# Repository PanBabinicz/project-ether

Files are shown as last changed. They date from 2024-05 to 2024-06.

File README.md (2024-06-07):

# PROJECT ETHER

## ❓ What is ETHER?

▶️ [Cambridge dictionary:](https://dictionary.cambridge.org/dictionary/english/ether)

> the sky or the air, especially considered as being full of radio waves

▶️ [The fantasy wiki with fictional characters:](https://gods-and-demons.fandom.com/wiki/Aether_(Deity))

> ***"Hi! My name is Aether and I am one of the Protogenoi. I'm the Lord of the stratosphere,
> or as I call it, the Upper Air, Bringer of Light, and the eldest son of Darkness and Night.
> Today, I will be your captain and guide as we explore the strange but fantastic world of Olympus.
> So hold tight to your seatbelts, 'cause this is gonna be one hell of a ride!"***
>
> Aether the god himself is the embodiment of the upper sky, the stratosphere is his domain and 
> with it the air that the gods breathe from. Every world has its own air for its creatures to breathe,
> the underworld is breathed by its monsters, the Human Realm is breathed by its humans, and the Skyland 
> is breathed by the divine beings who control reality; that is the air that Aether controls. It's not just 
> the air of Skyland that he controls however, a portion of the Earth's sky belongs to him as well. The Earthly sky 
> isn't the only cosmic body that Aether can control, the Moon, Stars, Clouds, and partially even the Sun can be controlled by him.

▶️ [The Concept of 'Ether' in Radio Wave Propagation:]

> In the context of radio waves, "ether" refers to the medium through which radio waves propagate.
> This medium is often conceptualized as the space surrounding us, particularly the atmosphere or the open air.
> In the early days of radio communication, scientists believed that radio waves traveled through a substance called
> "ether," filling the space much like air or water fills physical space. While the concept of a physical ether 
> was later debunked by advancements in physics, the term "ether" is still used metaphorically to describe the 
> invisible medium through which radio waves travel.

## ⚒️  Project goal 

> ***The main goal of the project is to create a comprehensive air quality monitoring system, 
> based on the ESP32 platform and integrated with OpenHAB and Grafana. The plan involves the development of 
> a dedicated hardware device equipped with ESP32, appropriate sensors measuring carbon dioxide, temperature, and humidity, 
> as well as a power supply unit. Additionally, the project envisages the use of the MQTT protocol,
> enabling efficient communication between devices, ensuring fast and reliable transmission of sensor data to the server.
> OpenHAB and Grafana will be deployed on the Raspberry Pi platform.***
>

> [!NOTE]
> **Please bear in mind that the project was primarily created for enjoyment and educational endeavors.**

## 🔌 Hardware

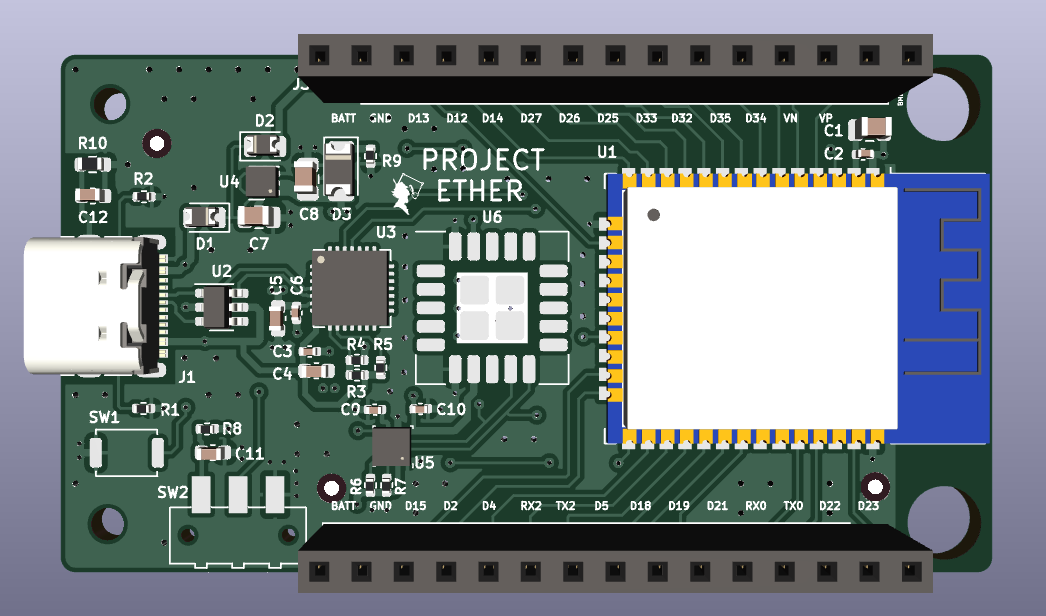
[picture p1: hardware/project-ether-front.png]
Front


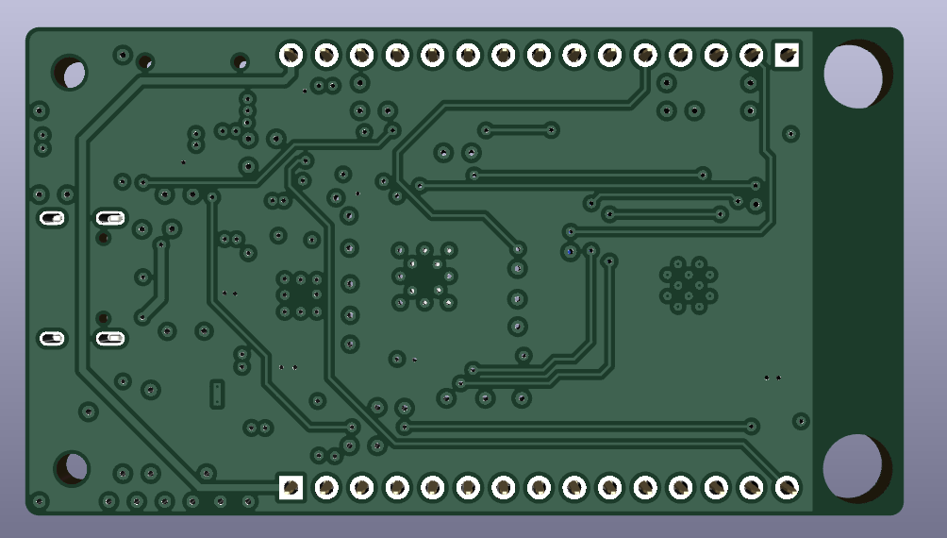
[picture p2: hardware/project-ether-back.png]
Back


> The hardware for this project was meticulously designed using KiCad, a popular open-source electronic design automation software. 
> The board is a 4-layer design featuring the ESP32-WROOM-32 module at its core. Additionally, it integrates key sensors such as the BME280 and SCD41,
> enabling environmental monitoring capabilities.
>
> The device can be conveniently powered either via USB Type-C connection or an external battery, providing flexibility for different usage scenarios and environments.

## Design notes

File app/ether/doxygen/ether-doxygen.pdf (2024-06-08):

## PROJECT ETHER

Generated by Doxygen 1.11.0

i

1 Data Structure Index | 1
2 File Index | 3
3 Data Structure Documentation | 5

Generated by Doxygen

ii

iii

iv

4 File Documentation | 27

v

vi

vii

viii

ix

x

Index | 81

# Chapter 1

# Data Structure Index

## 1.1 Data Structures

Here are the data structures with brief descriptions:

bme280_compensator_t

bme280_humidity_t

bme280_measurements_t

bme280_pressure_t

bme280_settings_t

bme280_temperature_t

ether_descriptor_t

ether_measurements_t

ether_settings_t

ether_state_machine_t

ether_t
Main structure for ETHER containing measurements, descriptors, settings, and state machine . 16 i2c_controller_descriptor_t

mqtt_controller_descriptor_t

pms7003_frame_answer_t

pms7003_frame_request_t

pms7003_measurements_t

uart_controller_descriptor_t

wifi_controller_descriptor_t

### 2 Data Structure Index

# Chapter 2

# File Index

## 2.1 File List

Here is a list of all files with brief descriptions:

### 4 File Index

# Chapter 3

# Data Structure Documentation

## 3.1 bme280_compensator_t Struct Reference

Structure for the BME280 sensor compensator data.

#include <bme280.h>

Data Fields

- uint16_t dig_t1
- int16_t dig_t2
- int16_t dig_t3
- uint16_t dig_p1
- int16_t dig_p2
- int16_t dig_p3
- int16_t dig_p4
- int16_t dig_p5
- int16_t dig_p6
- int16_t dig_p7
- int16_t dig_p8
- int16_t dig_p9
- uint8_t dig_h1
- int16_t dig_h2
- uint8_t dig_h3
- int16_t dig_h4
- int16_t dig_h5
- int8_t dig_h6

### 3.1.1 Detailed Description

Structure for the BME280 sensor compensator data.

### 6 Data Structure Documentation

### 3.1.2 Field Documentation

### 3.1.2.1 dig_h1

uint8_t dig_h1

Humidity compensation value H1.

### 3.1.2.2 dig_h2

int16_t dig_h2

Humidity compensation value H2.

### 3.1.2.3 dig_h3

uint8_t dig_h3

Humidity compensation value H3.

### 3.1.2.4 dig_h4

int16_t dig_h4

Humidity compensation value H4.

### 3.1.2.5 dig_h5

int16_t dig_h5

Humidity compensation value H5.

### 3.1.2.6 dig_h6

int8_t dig_h6

Humidity compensation value H6.

### 3.1.2.7 dig_p1

uint16_t dig_p1

Pressure compensation value P1.

3.1 bme280_compensator_t Struct Reference | 7

### 3.1.2.8 dig_p2

int16_t dig_p2

Pressure compensation value P2.

### 3.1.2.9 dig_p3

int16_t dig_p3

Pressure compensation value P3.

### 3.1.2.10 dig_p4

int16_t dig_p4

Pressure compensation value P4.

### 3.1.2.11 dig_p5

int16_t dig_p5

Pressure compensation value P5.

### 3.1.2.12 dig_p6

int16_t dig_p6

Pressure compensation value P6.

### 3.1.2.13 dig_p7

int16_t dig_p7

Pressure compensation value P7.

### 3.1.2.14 dig_p8

int16_t dig_p8

Pressure compensation value P8.

### 3.1.2.15 dig_p9

int16_t dig_p9

Pressure compensation value P9.

### 8 Data Structure Documentation

### 3.1.2.16 dig_t1

uint16_t dig_t1

Temperature compensation value T1.

### 3.1.2.17 dig_t2

int16_t dig_t2

Temperature compensation value T2.

### 3.1.2.18 dig_t3

int16_t dig_t3

Temperature compensation value T3.

The documentation for this struct was generated from the following file:

- bme280.h

## 3.2 bme280_humidity_t Struct Reference

Structure for the BME280 sensor humidity data.

#include <bme280.h>

Data Fields

- uint8_t msb
- uint8_t lsb
- double compensated

### 3.2.1 Detailed Description

Structure for the BME280 sensor humidity data.

### 3.2.2 Field Documentation

### 3.2.2.1 compensated

double compensated

Compensated humidity value.

3.3 bme280_measurements_t Struct Reference | 9

### 3.2.2.2 lsb

uint8_t lsb

Least significant byte.

### 3.2.2.3 msb

uint8_t msb

Most significant byte.

The documentation for this struct was generated from the following file:

- bme280.h

## 3.3 bme280_measurements_t Struct Reference

Structure for BME280 sensor measurements.

#include <bme280.h>

Data Fields

- bme280_humidity_t humidity
- bme280_pressure_t pressure
- bme280_temperature_t temperature
- bme280_compensator_t compensator

### 3.3.1 Detailed Description

Structure for BME280 sensor measurements.

### 3.3.2 Field Documentation

### 3.3.2.1 compensator

bme280_compensator_t compensator

Compensator data.

### 3.3.2.2 humidity

bme280_humidity_t humidity

Humidity data.

### 10 Data Structure Documentation

### 3.3.2.3 pressure

bme280_pressure_t pressure

Pressure data.

### 3.3.2.4 temperature

bme280_temperature_t temperature

Temperature data.

The documentation for this struct was generated from the following file:

- bme280.h

## 3.4 bme280_pressure_t Struct Reference

Structure for the BME280 sensor pressure data.

#include <bme280.h>

Data Fields

- uint8_t msb
- uint8_t lsb
- uint8_t xlsb
- double compensated

### 3.4.1 Detailed Description

Structure for the BME280 sensor pressure data.

### 3.4.2 Field Documentation

### 3.4.2.1 compensated

double compensated

Compensated pressure value.

### 3.4.2.2 lsb

uint8_t lsb

Least significant byte.

3.5 bme280_settings_t Struct Reference | 11

### 3.4.2.3 msb

uint8_t msb

Most significant byte.

### 3.4.2.4 xlsb

uint8_t xlsb

Extended least significant byte.

The documentation for this struct was generated from the following file:

- bme280.h

## 3.5 bme280_settings_t Struct Reference

Structure for the BME280 sensor settings.

#include <bme280.h>

Data Fields

- uint8_t ctrl_hum
- uint8_t ctrl_meas
- uint8_t config

### 3.5.1 Detailed Description

Structure for the BME280 sensor settings.

### 3.5.2 Field Documentation

### 3.5.2.1 config

uint8_t config

Configuration register value.

### 3.5.2.2 ctrl_hum

uint8_t ctrl_hum

Control humidity register value.

### 12 Data Structure Documentation

### 3.5.2.3 ctrl_meas

uint8_t ctrl_meas

Control measurement register value.

The documentation for this struct was generated from the following file:

- bme280.h

## 3.6 bme280_temperature_t Struct Reference

Structure for the BME280 sensor temperature data.

#include <bme280.h>

Data Fields

- uint8_t msb
- uint8_t lsb
- uint8_t xlsb
- double compensated

### 3.6.1 Detailed Description

Structure for the BME280 sensor temperature data.

### 3.6.2 Field Documentation

### 3.6.2.1 compensated

double compensated

Compensated temperature value.

### 3.6.2.2 lsb

uint8_t lsb

Least significant byte.

### 3.6.2.3 msb

uint8_t msb

Most significant byte.

3.7 ether_descriptor_t Struct Reference | 13

### 3.6.2.4 xlsb

uint8_t xlsb

Extended least significant byte.

The documentation for this struct was generated from the following file:

- bme280.h

## 3.7 ether_descriptor_t Struct Reference

Structure to hold various controller descriptors.

#include <ether.h>

Data Fields

- i2c_controller_descriptor_t i2c_controller
- mqtt_controller_descriptor_t mqtt_controller
- uart_controller_descriptor_t uart_controller
- wifi_controller_descriptor_t wifi_controller

### 3.7.1 Detailed Description

Structure to hold various controller descriptors.

### 3.7.2 Field Documentation

### 3.7.2.1 i2c_controller

i2c_controller_descriptor_t i2c_controller

I2C controller descriptor.

### 3.7.2.2 mqtt_controller

mqtt_controller_descriptor_t mqtt_controller

MQTT controller descriptor.

### 3.7.2.3 uart_controller

uart_controller_descriptor_t uart_controller

UART controller descriptor.

### 14 Data Structure Documentation

### 3.7.2.4 wifi_controller

wifi_controller_descriptor_t wifi_controller

WIFI controller descriptor.

The documentation for this struct was generated from the following file:

- ether.h

## 3.8 ether_measurements_t Struct Reference

Structure to store PMS7003 and BME280 sensors measurements.

#include <ether.h>

Data Fields

- pms7003_measurements_t pms7003
- bme280_measurements_t bme280

### 3.8.1 Detailed Description

Structure to store PMS7003 and BME280 sensors measurements.

### 3.8.2 Field Documentation

### 3.8.2.1 bme280

bme280_measurements_t bme280

BME280 measurements.

### 3.8.2.2 pms7003

pms7003_measurements_t pms7003

PMS7003 measurements.

The documentation for this struct was generated from the following file:

- ether.h

3.9 ether_settings_t Struct Reference | 15

## 3.9 ether_settings_t Struct Reference

Structure for ETHER settings.

#include <ether.h>

Data Fields

- bme280_settings_t bme280

### 3.9.1 Detailed Description

Structure for ETHER settings.

### 3.9.2 Field Documentation

### 3.9.2.1 bme280

bme280_settings_t bme280

BME280 sensor settings.

The documentation for this struct was generated from the following file:

- ether.h

## 3.10 ether_state_machine_t Struct Reference

Structure to hold the state machine for PMS7003 and BME280 sensors.

#include <ether.h>

Data Fields

- pms7003_state_t pms7003
- bme280_state_t bme280

### 3.10.1 Detailed Description

Structure to hold the state machine for PMS7003 and BME280 sensors.

### 16 Data Structure Documentation

### 3.10.2 Field Documentation

### 3.10.2.1 bme280

bme280_state_t bme280

BME280 sensor state.

### 3.10.2.2 pms7003

pms7003_state_t pms7003

PMS7003 sensor state.

The documentation for this struct was generated from the following file:

- ether.h

## 3.11 ether_t Struct Reference

Main structure for ETHER containing measurements, descriptors, settings, and state machine.

#include <ether.h>

Data Fields

- ether_measurements_t measurements
- ether_descriptor_t descriptor
- ether_settings_t settings
- ether_state_machine_t state_machine

### 3.11.1 Detailed Description

Main structure for ETHER containing measurements, descriptors, settings, and state machine.

### 3.11.2 Field Documentation

### 3.11.2.1 descriptor

ether_descriptor_t descriptor

Controller descriptors.

3.12 i2c_controller_descriptor_t Struct Reference | 17

### 3.11.2.2 measurements

ether_measurements_t measurements

Measurements data.

### 3.11.2.3 settings

ether_settings_t settings

Settings data.

### 3.11.2.4 state_machine

ether_state_machine_t state_machine

State machine data.

The documentation for this struct was generated from the following file:

- ether.h

## 3.12 i2c_controller_descriptor_t Struct Reference

Structure for I2C controller descriptor.

#include <i2c_controller.h>

Data Fields

- i2c_config_t config
- i2c_port_t i2c_num

### 3.12.1 Detailed Description

Structure for I2C controller descriptor.

### 3.12.2 Field Documentation

### 3.12.2.1 config

i2c_config_t config

I2C configuration.

### 18 Data Structure Documentation

### 3.12.2.2 i2c_num

i2c_port_t i2c_num

I2C port number.

The documentation for this struct was generated from the following file:

- i2c_controller.h

## 3.13 mqtt_controller_descriptor_t Struct Reference

Structure for MQTT controller descriptor.

#include <mqtt_controller.h>

Data Fields

- esp_mqtt_client_config_t client_config
- esp_mqtt_client_handle_t client_handle
- mqtt_controller_event_handler_t event_handler

### 3.13.1 Detailed Description

Structure for MQTT controller descriptor.

### 3.13.2 Field Documentation

### 3.13.2.1 client_config

esp_mqtt_client_config_t client_config

MQTT client configuration.

### 3.13.2.2 client_handle

esp_mqtt_client_handle_t client_handle

MQTT client handle.

### 3.13.2.3 event_handler

mqtt_controller_event_handler_t event_handler

MQTT event handler.

The documentation for this struct was generated from the following file:

- mqtt_controller.h

3.14 pms7003_frame_answer_t Union Reference | 19

## 3.14 pms7003_frame_answer_t Union Reference

Union representing a PMS7003 frame answer.

#include <pms7003.h>

Public Member Functions

- struct {
uint8_t start_byte_1
uint8_t start_byte_2
uint16_t length
uint16_t data_pm1_standard uint16_t data_pm25_standard uint16_t data_pm10_standard uint16_t data_pm1_atmospheric uint16_t data_pm25_atmospheric uint16_t data_concentration_unit uint16_t data_particles_300nm uint16_t data_particles_500nm uint16_t data_particles_1000nm uint16_t data_particles_2500nm uint16_t data_particles_5000nm uint16_t data_particles_10000nm uint16_t reserved
uint16_t check_code
} __attribute__ ((packed))

Data Fields

- uint8_t buffer_answer [PMS7003_FRAME_ANSWER_SIZE]

### 3.14.1 Detailed Description

Union representing a PMS7003 frame answer.

### 3.14.2 Member Function Documentation

### 3.14.2.1 __attribute__()

struct pms7003_frame_answer_t::@1 __attribute__ (

(packed) )

### 3.14.3 Field Documentation

### 3.14.3.1 buffer_answer

uint8_t buffer_answer[PMS7003_FRAME_ANSWER_SIZE]

Buffer for answer frame.

### 20 Data Structure Documentation

### 3.14.3.2 check_code

uint16_t check_code

Checksum code.

### 3.14.3.3 data_concentration_unit

uint16_t data_concentration_unit

Concentration unit.

### 3.14.3.4 data_particles_10000nm

uint16_t data_particles_10000nm

Particles count for 10µm.

### 3.14.3.5 data_particles_1000nm

uint16_t data_particles_1000nm

Particles count for 1.0µm.

### 3.14.3.6 data_particles_2500nm

uint16_t data_particles_2500nm

Particles count for 2.5µm.

### 3.14.3.7 data_particles_300nm

uint16_t data_particles_300nm

Particles count for 0.3µm.

### 3.14.3.8 data_particles_5000nm

uint16_t data_particles_5000nm

Particles count for 5.0µm.

### 3.14.3.9 data_particles_500nm

uint16_t data_particles_500nm

Particles count for 0.5µm.

3.14 pms7003_frame_answer_t Union Reference | 21

### 3.14.3.10 data_pm10_standard

uint16_t data_pm10_standard

PM10 concentration (standard particles).

### 3.14.3.11 data_pm1_atmospheric

uint16_t data_pm1_atmospheric

PM1.0 concentration (atmospheric particles).

### 3.14.3.12 data_pm1_standard

uint16_t data_pm1_standard

PM1.0 concentration (standard particles).

### 3.14.3.13 data_pm25_atmospheric

uint16_t data_pm25_atmospheric

PM2.5 concentration (atmospheric particles).

### 3.14.3.14 data_pm25_standard

uint16_t data_pm25_standard

PM2.5 concentration (standard particles).

### 3.14.3.15 length

uint16_t length

Length of the frame.

### 3.14.3.16 reserved

uint16_t reserved

Reserved bytes.

### 3.14.3.17 start_byte_1

uint8_t start_byte_1

Start byte 1.

### 22 Data Structure Documentation

### 3.14.3.18 start_byte_2

uint8_t start_byte_2

Start byte 2.

The documentation for this union was generated from the following file:

- pms7003.h

## 3.15 pms7003_frame_request_t Union Reference

Union representing a PMS7003 frame request.

#include <pms7003.h>

Public Member Functions

- struct {
const uint8_t start_byte_1 const uint8_t start_byte_2 uint8_t command
uint8_t data_h
uint8_t data_l
uint8_t lrch
uint8_t lrcl
} __attribute__ ((packed))

Data Fields

- uint8_t buffer_request [PMS7003_FRAME_REQUEST_SIZE]

### 3.15.1 Detailed Description

Union representing a PMS7003 frame request.

### 3.15.2 Member Function Documentation

### 3.15.2.1 __attribute__()

struct pms7003_frame_request_t::@0 __attribute__ (

(packed) )

3.15 pms7003_frame_request_t Union Reference | 23

### 3.15.3 Field Documentation

### 3.15.3.1 buffer_request

uint8_t buffer_request[PMS7003_FRAME_REQUEST_SIZE]

Buffer for request frame.

### 3.15.3.2 command

uint8_t command

Command byte.

### 3.15.3.3 data_h

uint8_t data_h

Data high byte.

### 3.15.3.4 data_l

uint8_t data_l

Data low byte.

### 3.15.3.5 lrch

uint8_t lrch

High byte of the checksum.

### 3.15.3.6 lrcl

uint8_t lrcl

Low byte of the checksum.

### 3.15.3.7 start_byte_1

const uint8_t start_byte_1

Start byte 1.

### 24 Data Structure Documentation

### 3.15.3.8 start_byte_2

const uint8_t start_byte_2

Start byte 2.

The documentation for this union was generated from the following file:

- pms7003.h

## 3.16 pms7003_measurements_t Struct Reference

Structure representing PMS7003 measurements.

#include <pms7003.h>

Data Fields

- uint16_t pm1
- uint16_t pm25
- uint16_t pm10

### 3.16.1 Detailed Description

Structure representing PMS7003 measurements.

### 3.16.2 Field Documentation

### 3.16.2.1 pm1

uint16_t pm1

PM1.0 measurement.

### 3.16.2.2 pm10

uint16_t pm10

PM10 measurement.

### 3.16.2.3 pm25

uint16_t pm25

PM2.5 measurement.

The documentation for this struct was generated from the following file:

- pms7003.h

3.17 uart_controller_descriptor_t Struct Reference | 25

## 3.17 uart_controller_descriptor_t Struct Reference

Structure for UART controller descriptor.

#include <uart_controller.h>

Data Fields

- uart_config_t uart_config
- uart_port_t uart_port

### 3.17.1 Detailed Description

Structure for UART controller descriptor.

### 3.17.2 Field Documentation

### 3.17.2.1 uart_config

uart_config_t uart_config

UART configuration.

### 3.17.2.2 uart_port

uart_port_t uart_port

UART port number.

The documentation for this struct was generated from the following file:

- uart_controller.h

## 3.18 wifi_controller_descriptor_t Struct Reference

Structure for WIFI controller descriptor.

#include <wifi_controller.h>

Data Fields

- wifi_config_t wifi_config
- wifi_controller_event_handler_t event_handler

### 26 Data Structure Documentation

### 3.18.1 Detailed Description

Structure for WIFI controller descriptor.

### 3.18.2 Field Documentation

### 3.18.2.1 event_handler

wifi_controller_event_handler_t event_handler

WIFI event handler.

### 3.18.2.2 wifi_config

wifi_config_t wifi_config

WIFI configuration.

The documentation for this struct was generated from the following file:

- wifi_controller.h

# Chapter 4

# File Documentation

## 4.1 bme280.h File Reference

#include <stddef.h>

#include <stdint.h>

#include "hal/i2c_types.h" #include "i2c_controller.h"

Data Structures

- struct bme280_settings_t

Structure for the BME280 sensor settings.
- struct bme280_pressure_t

Structure for the BME280 sensor pressure data.
- struct bme280_temperature_t

Structure for the BME280 sensor temperature data.
- struct bme280_humidity_t

Structure for the BME280 sensor humidity data.
- struct bme280_compensator_t

Structure for the BME280 sensor compensator data.
- struct bme280_measurements_t

Structure for BME280 sensor measurements.

Macros

- #define BME280_I2C_ADDRESS (0x76)
- #define BME280_REGISTER_ID (0xd0)
- #define BME280_REGISTER_RESET (0xe0)
- #define BME280_REGISTER_CTRL_HUM (0xf2)
- #define BME280_REGISTER_STATUS (0xf3)
- #define BME280_REGISTER_CTRL_MEAS (0xf4)
- #define BME280_REGISTER_CONFIG (0xf5)
- #define BME280_REGISTER_PRESS_MSB (0xf7)
- #define BME280_REGISTER_PRESS_LSB (0xf8)
- #define BME280_REGISTER_PRESS_XLSB (0xf9)

### 28 File Documentation

- #define BME280_REGISTER_TEMP_MSB (0xfa)
- #define BME280_REGISTER_TEMP_LSB (0xfb)
- #define BME280_REGISTER_TEMP_XLSB (0xfc)
- #define BME280_REGISTER_HUM_MSB (0xfd)
- #define BME280_REGISTER_HUM_LSB (0xfe)
- #define BME280_REGISTER_CALIB00 (0x88)
- #define BME280_REGISTER_CALIB01 (0x89)
- #define BME280_REGISTER_CALIB02 (0x8a)
- #define BME280_REGISTER_CALIB03 (0x8b)
- #define BME280_REGISTER_CALIB04 (0x8c)
- #define BME280_REGISTER_CALIB05 (0x8d)
- #define BME280_REGISTER_CALIB06 (0x8e)
- #define BME280_REGISTER_CALIB07 (0x8f)
- #define BME280_REGISTER_CALIB08 (0x90)
- #define BME280_REGISTER_CALIB09 (0x91)
- #define BME280_REGISTER_CALIB10 (0x92)
- #define BME280_REGISTER_CALIB11 (0x93)
- #define BME280_REGISTER_CALIB12 (0x94)
- #define BME280_REGISTER_CALIB13 (0x95)
- #define BME280_REGISTER_CALIB14 (0x96)
- #define BME280_REGISTER_CALIB15 (0x97)
- #define BME280_REGISTER_CALIB16 (0x98)
- #define BME280_REGISTER_CALIB17 (0x99)
- #define BME280_REGISTER_CALIB18 (0x9a)
- #define BME280_REGISTER_CALIB19 (0x9b)
- #define BME280_REGISTER_CALIB20 (0x9c)
- #define BME280_REGISTER_CALIB21 (0x9d)
- #define BME280_REGISTER_CALIB22 (0x9e)
- #define BME280_REGISTER_CALIB23 (0x9f)
- #define BME280_REGISTER_CALIB24 (0xa0)
- #define BME280_REGISTER_CALIB25 (0xa1)
- #define BME280_REGISTER_CALIB26 (0xe1)
- #define BME280_REGISTER_CALIB27 (0xe2)
- #define BME280_REGISTER_CALIB28 (0xe3)
- #define BME280_REGISTER_CALIB29 (0xe4)
- #define BME280_REGISTER_CALIB30 (0xe5)
- #define BME280_REGISTER_CALIB31 (0xe6)
- #define BME280_REGISTER_CALIB32 (0xe7)
- #define BME280_REGISTER_CALIB33 (0xe8)
- #define BME280_REGISTER_CALIB34 (0xe9)
- #define BME280_REGISTER_CALIB35 (0xea)
- #define BME280_REGISTER_CALIB36 (0xeb)
- #define BME280_REGISTER_CALIB37 (0xec)
- #define BME280_REGISTER_CALIB38 (0xed)
- #define BME280_REGISTER_CALIB39 (0xee)
- #define BME280_REGISTER_CALIB40 (0xef)
- #define BME280_REGISTER_CALIB41 (0xf0)
- #define BME280_DATA_RESET (0xb6)
- #define BME280_DATA_ID (0x60)
- #define BME280_SETTINGS_OSRS_H_SKIPPED (0 << 0)
- #define BME280_SETTINGS_OSRS_H_1 (1 << 0)
- #define BME280_SETTINGS_OSRS_H_2 (2 << 0)
- #define BME280_SETTINGS_OSRS_H_4 (3 << 0)
- #define BME280_SETTINGS_OSRS_H_8 (4 << 0)
- #define BME280_SETTINGS_OSRS_H_16 (5 << 0)

4.1 bme280.h File Reference | 29
- #define BME280_SETTINGS_OSRS_T_SKIPPED (0 << 5)
- #define BME280_SETTINGS_OSRS_T_1 (1 << 5)
- #define BME280_SETTINGS_OSRS_T_2 (2 << 5)
- #define BME280_SETTINGS_OSRS_T_4 (3 << 5)
- #define BME280_SETTINGS_OSRS_T_8 (4 << 5)
- #define BME280_SETTINGS_OSRS_T_16 (5 << 5)
- #define BME280_SETTINGS_OSRS_P_SKIPPED (0 << 2)
- #define BME280_SETTINGS_OSRS_P_1 (1 << 2)
- #define BME280_SETTINGS_OSRS_P_2 (2 << 2)
- #define BME280_SETTINGS_OSRS_P_4 (3 << 2)
- #define BME280_SETTINGS_OSRS_P_8 (4 << 2)
- #define BME280_SETTINGS_OSRS_P_16 (5 << 2)
- #define BME280_SETTINGS_MODE_SLEEP (0 << 0)
- #define BME280_SETTINGS_MODE_FORCE (1 << 0)
- #define BME280_SETTINGS_MODE_NORMAL (3 << 0)
- #define BME280_I2C_ACK_ENABLE (0x01)
- #define BME280_I2C_ACK_DISABLE (0x00)
- #define BME280_SIZE_HUM (0x02)
- #define BME280_SIZE_PRESS (0x03)
- #define BME280_SIZE_TEMP (0x03)
- #define BME280_SIZE_COMP (0x21)
- #define BME280_SETTINGS_DEFAULT

Enumerations

- enum bme280_result_t { BME280_RESULT_SUCCESS = 0 , BME280_RESULT_ERROR }

Result codes for BME280 sensor operations.
- enum bme280_state_t {
BME280_STATE_INIT = 0 , BME280_STATE_RESET , BME280_STATE_ID , BME280_STATE_FORCE_MODE
,
BME280_STATE_MEASURE_HUMIDITY , BME280_STATE_MEASURE_TEMPERATURE , BME280_STATE_MEASURE_PRESSURE , BME280_STATE_GET_COMPENSATION_DATA ,
BME280_STATE_COMPENSATE_HUMIDITY | , | BME280_STATE_COMPENSATE_TEMPERATURE | ,
BME280_STATE_COMPENSATE_PRESSURE , BME280_STATE_UNSET = 0xFF }

State codes for BME280 sensor initialization and operations.

Functions

- bme280_result_t bme280_init (i2c_port_t i2c_num, const bme280_settings_t ∗settings)

Initialize the BME280 sensor.
- bme280_result_t bme280_reset (i2c_port_t i2c_num)

Reset the BME280 sensor.
- bme280_result_t bme280_id (i2c_port_t i2c_num, uint8_t ∗data, size_t data_len)

Read the sensor ID.
- bme280_result_t bme280_force_mode (i2c_port_t i2c_num, const bme280_settings_t ∗settings)

Set the sensor to force mode.
- bme280_result_t bme280_measure_humidity (i2c_port_t i2c_num, bme280_humidity_t ∗humidity)

Measure humidity.
- bme280_result_t bme280_measure_temperature (i2c_port_t i2c_num, bme280_temperature_t ∗temperature)

Measure temperature.
- bme280_result_t bme280_measure_pressure (i2c_port_t i2c_num, bme280_pressure_t ∗pressure)

Measure pressure.

### 30 File Documentation

- bme280_result_t bme280_get_compensation_data (i2c_port_t i2c_num, bme280_compensator_t ∗compensator)

Get sensor compensation data.
- bme280_result_t bme280_compensate_humidity (bme280_compensator_t ∗compensator, bme280_humidity_t ∗humidity)

Compensate the humidity measurement.
- bme280_result_t bme280_compensate_temperature (bme280_compensator_t ∗compensator, bme280_temperature_t ∗temperature)

Compensate the temperature measurement.
- bme280_result_t bme280_compensate_pressure (bme280_compensator_t ∗compensator, bme280_pressure_t ∗pressure)

Compensate the pressure measurement.

### 4.1.1 Macro Definition Documentation

### 4.1.1.1 BME280_DATA_ID

#define BME280_DATA_ID (0x60)

### 4.1.1.2 BME280_DATA_RESET

#define BME280_DATA_RESET (0xb6)

### 4.1.1.3 BME280_I2C_ACK_DISABLE

#define BME280_I2C_ACK_DISABLE (0x00)

### 4.1.1.4 BME280_I2C_ACK_ENABLE

#define BME280_I2C_ACK_ENABLE (0x01)

### 4.1.1.5 BME280_I2C_ADDRESS

#define BME280_I2C_ADDRESS (0x76)

### 4.1.1.6 BME280_REGISTER_CALIB00

#define BME280_REGISTER_CALIB00 (0x88)

### 4.1.1.7 BME280_REGISTER_CALIB01

#define BME280_REGISTER_CALIB01 (0x89)

4.1 bme280.h File Reference | 31

### 4.1.1.8 BME280_REGISTER_CALIB02

#define BME280_REGISTER_CALIB02 (0x8a)

### 4.1.1.9 BME280_REGISTER_CALIB03

#define BME280_REGISTER_CALIB03 (0x8b)

### 4.1.1.10 BME280_REGISTER_CALIB04

#define BME280_REGISTER_CALIB04 (0x8c)

### 4.1.1.11 BME280_REGISTER_CALIB05

#define BME280_REGISTER_CALIB05 (0x8d)

### 4.1.1.12 BME280_REGISTER_CALIB06

#define BME280_REGISTER_CALIB06 (0x8e)

### 4.1.1.13 BME280_REGISTER_CALIB07

#define BME280_REGISTER_CALIB07 (0x8f)

### 4.1.1.14 BME280_REGISTER_CALIB08

#define BME280_REGISTER_CALIB08 (0x90)

### 4.1.1.15 BME280_REGISTER_CALIB09

#define BME280_REGISTER_CALIB09 (0x91)

### 4.1.1.16 BME280_REGISTER_CALIB10

#define BME280_REGISTER_CALIB10 (0x92)

### 4.1.1.17 BME280_REGISTER_CALIB11

#define BME280_REGISTER_CALIB11 (0x93)

### 32 File Documentation

### 4.1.1.18 BME280_REGISTER_CALIB12

#define BME280_REGISTER_CALIB12 (0x94)

### 4.1.1.19 BME280_REGISTER_CALIB13

#define BME280_REGISTER_CALIB13 (0x95)

### 4.1.1.20 BME280_REGISTER_CALIB14

#define BME280_REGISTER_CALIB14 (0x96)

### 4.1.1.21 BME280_REGISTER_CALIB15

#define BME280_REGISTER_CALIB15 (0x97)

### 4.1.1.22 BME280_REGISTER_CALIB16

#define BME280_REGISTER_CALIB16 (0x98)

### 4.1.1.23 BME280_REGISTER_CALIB17

#define BME280_REGISTER_CALIB17 (0x99)

### 4.1.1.24 BME280_REGISTER_CALIB18

#define BME280_REGISTER_CALIB18 (0x9a)

### 4.1.1.25 BME280_REGISTER_CALIB19

#define BME280_REGISTER_CALIB19 (0x9b)

### 4.1.1.26 BME280_REGISTER_CALIB20

#define BME280_REGISTER_CALIB20 (0x9c)

### 4.1.1.27 BME280_REGISTER_CALIB21

#define BME280_REGISTER_CALIB21 (0x9d)

4.1 bme280.h File Reference | 33

### 4.1.1.28 BME280_REGISTER_CALIB22

#define BME280_REGISTER_CALIB22 (0x9e)

### 4.1.1.29 BME280_REGISTER_CALIB23

#define BME280_REGISTER_CALIB23 (0x9f)

### 4.1.1.30 BME280_REGISTER_CALIB24

#define BME280_REGISTER_CALIB24 (0xa0)

### 4.1.1.31 BME280_REGISTER_CALIB25

#define BME280_REGISTER_CALIB25 (0xa1)

### 4.1.1.32 BME280_REGISTER_CALIB26

#define BME280_REGISTER_CALIB26 (0xe1)

### 4.1.1.33 BME280_REGISTER_CALIB27

#define BME280_REGISTER_CALIB27 (0xe2)

### 4.1.1.34 BME280_REGISTER_CALIB28

#define BME280_REGISTER_CALIB28 (0xe3)

### 4.1.1.35 BME280_REGISTER_CALIB29

#define BME280_REGISTER_CALIB29 (0xe4)

### 4.1.1.36 BME280_REGISTER_CALIB30

#define BME280_REGISTER_CALIB30 (0xe5)

### 4.1.1.37 BME280_REGISTER_CALIB31

#define BME280_REGISTER_CALIB31 (0xe6)

### 34 File Documentation

### 4.1.1.38 BME280_REGISTER_CALIB32

#define BME280_REGISTER_CALIB32 (0xe7)

### 4.1.1.39 BME280_REGISTER_CALIB33

#define BME280_REGISTER_CALIB33 (0xe8)

### 4.1.1.40 BME280_REGISTER_CALIB34

#define BME280_REGISTER_CALIB34 (0xe9)

### 4.1.1.41 BME280_REGISTER_CALIB35

#define BME280_REGISTER_CALIB35 (0xea)

### 4.1.1.42 BME280_REGISTER_CALIB36

#define BME280_REGISTER_CALIB36 (0xeb)

### 4.1.1.43 BME280_REGISTER_CALIB37

#define BME280_REGISTER_CALIB37 (0xec)

### 4.1.1.44 BME280_REGISTER_CALIB38

#define BME280_REGISTER_CALIB38 (0xed)

### 4.1.1.45 BME280_REGISTER_CALIB39

#define BME280_REGISTER_CALIB39 (0xee)

### 4.1.1.46 BME280_REGISTER_CALIB40

#define BME280_REGISTER_CALIB40 (0xef)

### 4.1.1.47 BME280_REGISTER_CALIB41

#define BME280_REGISTER_CALIB41 (0xf0)

4.1 bme280.h File Reference | 35

### 4.1.1.48 BME280_REGISTER_CONFIG

#define BME280_REGISTER_CONFIG (0xf5)

### 4.1.1.49 BME280_REGISTER_CTRL_HUM

#define BME280_REGISTER_CTRL_HUM (0xf2)

### 4.1.1.50 BME280_REGISTER_CTRL_MEAS

#define BME280_REGISTER_CTRL_MEAS (0xf4)

### 4.1.1.51 BME280_REGISTER_HUM_LSB

#define BME280_REGISTER_HUM_LSB (0xfe)

### 4.1.1.52 BME280_REGISTER_HUM_MSB

#define BME280_REGISTER_HUM_MSB (0xfd)

### 4.1.1.53 BME280_REGISTER_ID

#define BME280_REGISTER_ID (0xd0)

### 4.1.1.54 BME280_REGISTER_PRESS_LSB

#define BME280_REGISTER_PRESS_LSB (0xf8)

### 4.1.1.55 BME280_REGISTER_PRESS_MSB

#define BME280_REGISTER_PRESS_MSB (0xf7)

### 4.1.1.56 BME280_REGISTER_PRESS_XLSB

#define BME280_REGISTER_PRESS_XLSB (0xf9)

### 4.1.1.57 BME280_REGISTER_RESET

#define BME280_REGISTER_RESET (0xe0)

### 36 File Documentation

### 4.1.1.58 BME280_REGISTER_STATUS

#define BME280_REGISTER_STATUS (0xf3)

### 4.1.1.59 BME280_REGISTER_TEMP_LSB

#define BME280_REGISTER_TEMP_LSB (0xfb)

### 4.1.1.60 BME280_REGISTER_TEMP_MSB

#define BME280_REGISTER_TEMP_MSB (0xfa)

### 4.1.1.61 BME280_REGISTER_TEMP_XLSB

#define BME280_REGISTER_TEMP_XLSB (0xfc)

### 4.1.1.62 BME280_SETTINGS_DEFAULT

#define BME280_SETTINGS_DEFAULT

Value:
{ | \
.ctrl_hum = BME280_SETTINGS_OSRS_H_1, | \
.ctrl_meas = (BME280_SETTINGS_OSRS_T_1 | BME280_SETTINGS_OSRS_P_1 | \
BME280_SETTINGS_MODE_FORCE), | \
.config = 0x00, | \
}

Suggested settings for weather monitoring; Sensor mode: force mode, 1 sample per minute;

### 4.1.1.63 BME280_SETTINGS_MODE_FORCE

#define BME280_SETTINGS_MODE_FORCE (1 << 0)

### 4.1.1.64 BME280_SETTINGS_MODE_NORMAL

#define BME280_SETTINGS_MODE_NORMAL (3 << 0)

### 4.1.1.65 BME280_SETTINGS_MODE_SLEEP

#define BME280_SETTINGS_MODE_SLEEP (0 << 0)

### 4.1.1.66 BME280_SETTINGS_OSRS_H_1

#define BME280_SETTINGS_OSRS_H_1 (1 << 0)

4.1 bme280.h File Reference | 37

### 4.1.1.67 BME280_SETTINGS_OSRS_H_16

#define BME280_SETTINGS_OSRS_H_16 (5 << 0)

### 4.1.1.68 BME280_SETTINGS_OSRS_H_2

#define BME280_SETTINGS_OSRS_H_2 (2 << 0)

### 4.1.1.69 BME280_SETTINGS_OSRS_H_4

#define BME280_SETTINGS_OSRS_H_4 (3 << 0)

### 4.1.1.70 BME280_SETTINGS_OSRS_H_8

#define BME280_SETTINGS_OSRS_H_8 (4 << 0)

### 4.1.1.71 BME280_SETTINGS_OSRS_H_SKIPPED

#define BME280_SETTINGS_OSRS_H_SKIPPED (0 << 0)

### 4.1.1.72 BME280_SETTINGS_OSRS_P_1

#define BME280_SETTINGS_OSRS_P_1 (1 << 2)

### 4.1.1.73 BME280_SETTINGS_OSRS_P_16

#define BME280_SETTINGS_OSRS_P_16 (5 << 2)

### 4.1.1.74 BME280_SETTINGS_OSRS_P_2

#define BME280_SETTINGS_OSRS_P_2 (2 << 2)

### 4.1.1.75 BME280_SETTINGS_OSRS_P_4

#define BME280_SETTINGS_OSRS_P_4 (3 << 2)

### 4.1.1.76 BME280_SETTINGS_OSRS_P_8

#define BME280_SETTINGS_OSRS_P_8 (4 << 2)

### 38 File Documentation

### 4.1.1.77 BME280_SETTINGS_OSRS_P_SKIPPED

#define BME280_SETTINGS_OSRS_P_SKIPPED (0 << 2)

### 4.1.1.78 BME280_SETTINGS_OSRS_T_1

#define BME280_SETTINGS_OSRS_T_1 (1 << 5)

### 4.1.1.79 BME280_SETTINGS_OSRS_T_16

#define BME280_SETTINGS_OSRS_T_16 (5 << 5)

### 4.1.1.80 BME280_SETTINGS_OSRS_T_2

#define BME280_SETTINGS_OSRS_T_2 (2 << 5)

### 4.1.1.81 BME280_SETTINGS_OSRS_T_4

#define BME280_SETTINGS_OSRS_T_4 (3 << 5)

### 4.1.1.82 BME280_SETTINGS_OSRS_T_8

#define BME280_SETTINGS_OSRS_T_8 (4 << 5)

### 4.1.1.83 BME280_SETTINGS_OSRS_T_SKIPPED

#define BME280_SETTINGS_OSRS_T_SKIPPED (0 << 5)

### 4.1.1.84 BME280_SIZE_COMP

#define BME280_SIZE_COMP (0x21)

### 4.1.1.85 BME280_SIZE_HUM

#define BME280_SIZE_HUM (0x02)

### 4.1.1.86 BME280_SIZE_PRESS

#define BME280_SIZE_PRESS (0x03)

### 4.1.1.87 BME280_SIZE_TEMP

#define BME280_SIZE_TEMP (0x03)

### 4.1.2 Enumeration Type Documentation

### 4.1.2.1 bme280_result_t

enum bme280_result_t

Result codes for BME280 sensor operations.

4.1 bme280.h File Reference | 39

Enumerator

BME280_RESULT_SUCCESS | Operation was successful.
BME280_RESULT_ERROR | Operation encountered an error.

### 4.1.2.2 bme280_state_t

enum bme280_state_t

State codes for BME280 sensor initialization and operations.

Enumerator

BME280_STATE_INIT | Initial state.
BME280_STATE_RESET | Reset state.
BME280_STATE_ID | ID reading state.
BME280_STATE_FORCE_MODE | Force mode state.
BME280_STATE_MEASURE_HUMIDITY | Humidity measurement state.
BME280_STATE_MEASURE_TEMPERATURE | Temperature measurement state.
BME280_STATE_MEASURE_PRESSURE | Pressure measurement state.
BME280_STATE_GET_COMPENSATION_DATA | Compensation data retrieval state.
BME280_STATE_COMPENSATE_HUMIDITY | Humidity compensation state.
BME280_STATE_COMPENSATE_TEMPERATURE | Temperature compensation state.
BME280_STATE_COMPENSATE_PRESSURE | Pressure compensation state.
BME280_STATE_UNSET | Unset state.

### 4.1.3 Function Documentation

### 4.1.3.1 bme280_compensate_humidity()

bme280_result_t bme280_compensate_humidity (

bme280_compensator_t ∗ compensator,

bme280_humidity_t ∗ humidity)

Compensate the humidity measurement.

Parameters

in | compensator | Pointer to compensator structure with calibration data.
out | humidity | Pointer to humidity structure to store compensated value.

Returns

Result of the humidity compensation.

### 4.1.3.2 bme280_compensate_pressure()

bme280_result_t bme280_compensate_pressure (

bme280_compensator_t ∗ compensator,

bme280_pressure_t ∗ pressure)

Compensate the pressure measurement.

### 40 File Documentation

Parameters

in | compensator | Pointer to compensator structure with calibration data.
out | pressure | Pointer to pressure structure to store compensated value.

Returns

Result of the pressure compensation.

### 4.1.3.3 bme280_compensate_temperature()

bme280_result_t bme280_compensate_temperature (

bme280_compensator_t ∗ compensator,

bme280_temperature_t ∗ temperature)

Compensate the temperature measurement.

Parameters

in | compensator | Pointer to compensator structure with calibration data.
out | temperature | Pointer to temperature structure to store compensated value.

Returns

Result of the temperature compensation.

### 4.1.3.4 bme280_force_mode()

bme280_result_t bme280_force_mode (

i2c_port_t i2c_num,

const bme280_settings_t ∗ settings)

Set the sensor to force mode.

Parameters

in | i2c_num | I2C port number.
in | settings | Pointer to sensor settings structure.

Returns

Result of the operation.

### 4.1.3.5 bme280_get_compensation_data()

bme280_result_t bme280_get_compensation_data (

i2c_port_t i2c_num,

bme280_compensator_t ∗ compensator)

Get sensor compensation data.

4.1 bme280.h File Reference | 41

Parameters

in | i2c_num | I2C port number.
out | compensator | Pointer to compensator structure to store the data.

Returns

Result of the compensation data retrieval.

### 4.1.3.6 bme280_id()

bme280_result_t bme280_id (

i2c_port_t i2c_num,

uint8_t ∗ data,

size_t data_len)

Read the sensor ID.

Parameters

in | i2c_num | I2C port number.
out | data | Pointer to buffer to store ID data.
in | data_len | Length of the buffer.

Returns

Result of the ID read operation.

### 4.1.3.7 bme280_init()

bme280_result_t bme280_init (

i2c_port_t i2c_num,

const bme280_settings_t ∗ settings)

Initialize the BME280 sensor.

Parameters

in | i2c_num | I2C port number.
in | settings | Pointer to sensor settings structure.

Returns

Result of the initialization.

### 4.1.3.8 bme280_measure_humidity()

bme280_result_t bme280_measure_humidity (

i2c_port_t i2c_num,

bme280_humidity_t ∗ humidity)

Measure humidity.

### 42 File Documentation

Parameters

in | i2c_num | I2C port number.
out | humidity | Pointer to humidity structure to store the measurement.

Returns

Result of the humidity measurement.

### 4.1.3.9 bme280_measure_pressure()

bme280_result_t bme280_measure_pressure (

i2c_port_t i2c_num,

bme280_pressure_t ∗ pressure)

Measure pressure.

Parameters

in | i2c_num | I2C port number.
out | pressure | Pointer to pressure structure to store the measurement.

Returns

Result of the pressure measurement.

### 4.1.3.10 bme280_measure_temperature()

bme280_result_t bme280_measure_temperature (

i2c_port_t i2c_num,

bme280_temperature_t ∗ temperature)

Measure temperature.

Parameters

in | i2c_num | I2C port number.
out | temperature | Pointer to temperature structure to store the measurement.

Returns

Result of the temperature measurement.

### 4.1.3.11 bme280_reset()

bme280_result_t bme280_reset (

i2c_port_t i2c_num)

Reset the BME280 sensor.

4.2 bme280.h | 43

Parameters

in | i2c_num | I2C port number.

Returns

Result of the reset operation.

## 4.2 bme280.h

Go to the documentation of this file.

00001 #ifndef INC_BME280_H
00002 #define INC_BME280_H
00003
00004 #include <stddef.h>
00005 #include <stdint.h>
00006 #include "hal/i2c_types.h" 00007 #include "i2c_controller.h
"
00008
00009 #define BME280_I2C_ADDRESS (0x76)
00010
00011 #define BME280_REGISTER_ID | (0xd0)
00012 #define BME280_REGISTER_RESET | (0xe0)
00013 #define BME280_REGISTER_CTRL_HUM | (0xf2)
00014 #define BME280_REGISTER_STATUS | (0xf3)
00015 #define BME280_REGISTER_CTRL_MEAS | (0xf4)
00016 #define BME280_REGISTER_CONFIG | (0xf5)
00017 #define BME280_REGISTER_PRESS_MSB | (0xf7)
00018 #define BME280_REGISTER_PRESS_LSB | (0xf8)
00019 #define BME280_REGISTER_PRESS_XLSB | (0xf9)
00020 #define BME280_REGISTER_TEMP_MSB | (0xfa)
00021 #define BME280_REGISTER_TEMP_LSB | (0xfb)
00022 #define BME280_REGISTER_TEMP_XLSB | (0xfc)
00023 #define BME280_REGISTER_HUM_MSB | (0xfd)
00024 #define BME280_REGISTER_HUM_LSB | (0xfe)
00025
00026 #define BME280_REGISTER_CALIB00 | (0x88)
00027 #define BME280_REGISTER_CALIB01 | (0x89)
00028 #define BME280_REGISTER_CALIB02 | (0x8a)
00029 #define BME280_REGISTER_CALIB03 | (0x8b)
00030 #define BME280_REGISTER_CALIB04 | (0x8c)
00031 #define BME280_REGISTER_CALIB05 | (0x8d)
00032 #define BME280_REGISTER_CALIB06 | (0x8e)
00033 #define BME280_REGISTER_CALIB07 | (0x8f)
00034 #define BME280_REGISTER_CALIB08 | (0x90)
00035 #define BME280_REGISTER_CALIB09 | (0x91)
00036 #define BME280_REGISTER_CALIB10 | (0x92)
00037 #define BME280_REGISTER_CALIB11 | (0x93)
00038 #define BME280_REGISTER_CALIB12 | (0x94)
00039 #define BME280_REGISTER_CALIB13 | (0x95)
00040 #define BME280_REGISTER_CALIB14 | (0x96)
00041 #define BME280_REGISTER_CALIB15 | (0x97)
00042 #define BME280_REGISTER_CALIB16 | (0x98)
00043 #define BME280_REGISTER_CALIB17 | (0x99)
00044 #define BME280_REGISTER_CALIB18 | (0x9a)
00045 #define BME280_REGISTER_CALIB19 | (0x9b)
00046 #define BME280_REGISTER_CALIB20 | (0x9c)
00047 #define BME280_REGISTER_CALIB21 | (0x9d)
00048 #define BME280_REGISTER_CALIB22 | (0x9e)
00049 #define BME280_REGISTER_CALIB23 | (0x9f)
00050 #define BME280_REGISTER_CALIB24 | (0xa0)
00051 #define BME280_REGISTER_CALIB25 | (0xa1)
00052 #define BME280_REGISTER_CALIB26 | (0xe1)
00053 #define BME280_REGISTER_CALIB27 | (0xe2)
00054 #define BME280_REGISTER_CALIB28 | (0xe3)
00055 #define BME280_REGISTER_CALIB29 | (0xe4)
00056 #define BME280_REGISTER_CALIB30 | (0xe5)
00057 #define BME280_REGISTER_CALIB31 | (0xe6)
00058 #define BME280_REGISTER_CALIB32 | (0xe7)
00059 #define BME280_REGISTER_CALIB33 | (0xe8)
00060 #define BME280_REGISTER_CALIB34 | (0xe9)
00061 #define BME280_REGISTER_CALIB35 | (0xea)
00062 #define BME280_REGISTER_CALIB36 | (0xeb)
00063 #define BME280_REGISTER_CALIB37 | (0xec)
00064 #define BME280_REGISTER_CALIB38 | (0xed)
00065 #define BME280_REGISTER_CALIB39 | (0xee)

### 44 File Documentation

00066 #define BME280_REGISTER_CALIB40 | (0xef)
00067 #define BME280_REGISTER_CALIB41 | (0xf0)
00068
00069 #define BME280_DATA_RESET (0xb6)
00070 #define BME280_DATA_ID | (0x60)
00071
00072 #define BME280_SETTINGS_OSRS_H_SKIPPED | (0 « 0)
00073 #define BME280_SETTINGS_OSRS_H_1 | (1 « 0)
00074 #define BME280_SETTINGS_OSRS_H_2 | (2 « 0)
00075 #define BME280_SETTINGS_OSRS_H_4 | (3 « 0)
00076 #define BME280_SETTINGS_OSRS_H_8 | (4 « 0)
00077 #define BME280_SETTINGS_OSRS_H_16 | (5 « 0)
00078
00079 #define BME280_SETTINGS_OSRS_T_SKIPPED | (0 « 5)
00080 #define BME280_SETTINGS_OSRS_T_1 | (1 « 5)
00081 #define BME280_SETTINGS_OSRS_T_2 | (2 « 5)
00082 #define BME280_SETTINGS_OSRS_T_4 | (3 « 5)
00083 #define BME280_SETTINGS_OSRS_T_8 | (4 « 5)
00084 #define BME280_SETTINGS_OSRS_T_16 | (5 « 5)
00085
00086 #define BME280_SETTINGS_OSRS_P_SKIPPED | (0 « 2)
00087 #define BME280_SETTINGS_OSRS_P_1 | (1 « 2)
00088 #define BME280_SETTINGS_OSRS_P_2 | (2 « 2)
00089 #define BME280_SETTINGS_OSRS_P_4 | (3 « 2)
00090 #define BME280_SETTINGS_OSRS_P_8 | (4 « 2)
00091 #define BME280_SETTINGS_OSRS_P_16 | (5 « 2)
00092
00093 #define BME280_SETTINGS_MODE_SLEEP | (0 « 0)
00094 #define BME280_SETTINGS_MODE_FORCE | (1 « 0)
00095 #define BME280_SETTINGS_MODE_NORMAL | (3 « 0)
00096
00097 #define BME280_I2C_ACK_ENABLE | (0x01)
00098 #define BME280_I2C_ACK_DISABLE | (0x00)
00099
00100 #define BME280_SIZE_HUM (0x02) 00101 #define BME280_SIZE_PRESS (0x03)
00102 #define BME280_SIZE_TEMP | (0x03)
00103 #define BME280_SIZE_COMP | (0x21)
00104
00108 typedef enum {
00109 | BME280_RESULT_SUCCESS = 0,
00110 | BME280_RESULT_ERROR,
00111 } bme280_result_t;
00112
00116 typedef enum {
00117 | BME280_STATE_INIT = 0,
00118 | BME280_STATE_RESET,
00119 | BME280_STATE_ID,
00120 | BME280_STATE_FORCE_MODE,
00121 | BME280_STATE_MEASURE_HUMIDITY,
00122 | BME280_STATE_MEASURE_TEMPERATURE,
00123 | BME280_STATE_MEASURE_PRESSURE,
00124 | BME280_STATE_GET_COMPENSATION_DATA,
00125 | BME280_STATE_COMPENSATE_HUMIDITY,
00126 | BME280_STATE_COMPENSATE_TEMPERATURE,
00127 | BME280_STATE_COMPENSATE_PRESSURE,
00128 | BME280_STATE_UNSET = 0xFF,
00129 } bme280_state_t;
00130
00134 typedef struct {
00135 | uint8_t ctrl_hum;
00136 | uint8_t ctrl_meas;
00137 | uint8_t config;
00138 } bme280_settings_t; 00139
00143 typedef struct {
00144 | uint8_t msb;
00145 | uint8_t lsb;
00146 | uint8_t xlsb;
00147 | double | compensated;
00148 } bme280_pressure_t; 00149
00153 typedef struct {
00154 | uint8_t msb;
00155 | uint8_t lsb;
00156 | uint8_t xlsb;
00157 | double | compensated;
00158 } bme280_temperature_t; 00159
00163 typedef struct {
00164 | uint8_t msb;
00165 | uint8_t lsb;
00166 | double | compensated;
00167 } bme280_humidity_t; 00168
00172 typedef struct {
00173 | uint16_t | dig_t1;

4.3 ether.h File Reference | 45
00174 | int16_t | dig_t2;
00175 | int16_t | dig_t3;
00176 | uint16_t | dig_p1;
00177 | int16_t | dig_p2;
00178 | int16_t | dig_p3;
00179 | int16_t | dig_p4;
00180 | int16_t | dig_p5;
00181 | int16_t | dig_p6;
00182 | int16_t | dig_p7;
00183 | int16_t | dig_p8;
00184 | int16_t | dig_p9;
00185 | uint8_t | dig_h1;
00186 | int16_t | dig_h2;
00187 | uint8_t | dig_h3;
00188 | int16_t | dig_h4;
00189 | int16_t | dig_h5;
00190 | int8_t | dig_h6;
00191 } bme280_compensator_t; 00192
00196 typedef struct {
00197 | bme280_humidity_t humidity;
00198 | bme280_pressure_t pressure;
00199 | bme280_temperature_t temperature;
00200 | bme280_compensator_t compensator;
00201 } bme280_measurements_t;
00202
00207 #define BME280_SETTINGS_DEFAULT { | \
00208 | .ctrl_hum = BME280_SETTINGS_OSRS_H_1, | \
00209 | .ctrl_meas = (BME280_SETTINGS_OSRS_T_1 | BME280_SETTINGS_OSRS_P_1 | \
00210 | BME280_SETTINGS_MODE_FORCE), | \
00211 | .config = 0x00, | \
00212 }
00213
00221 bme280_result_t bme280_init(i2c_port_t i2c_num, const bme280_settings_t *settings); 00222
00229 bme280_result_t bme280_reset(i2c_port_t i2c_num);
00230
00239 bme280_result_t bme280_id(i2c_port_t i2c_num, uint8_t *data, size_t data_len);
00240
00248 bme280_result_t bme280_force_mode(i2c_port_t i2c_num, const bme280_settings_t *settings); 00249
00257 bme280_result_t bme280_measure_humidity(i2c_port_t i2c_num, bme280_humidity_t *humidity); 00258
00266 bme280_result_t bme280_measure_temperature(i2c_port_t i2c_num,
00267 | bme280_temperature_t *temperature);
00268
00276 bme280_result_t bme280_measure_pressure(i2c_port_t i2c_num, bme280_pressure_t *pressure); 00277
00285 bme280_result_t bme280_get_compensation_data(i2c_port_t i2c_num,
00286 | bme280_compensator_t *compensator);
00287
00295 bme280_result_t bme280_compensate_humidity(bme280_compensator_t *compensator,
00296 | bme280_humidity_t *humidity);
00297
00305 bme280_result_t bme280_compensate_temperature(bme280_compensator_t *compensator,
00306 | bme280_temperature_t *temperature);
00307
00315 bme280_result_t bme280_compensate_pressure(bme280_compensator_t *compensator,
00316 | bme280_pressure_t *pressure);
00317
00318 #endif // !INC_BME280_H

## 4.3 ether.h File Reference

#include "freertos/FreeRTOS.h" #include "freertos/projdefs.h" #include "freertos/task.h" #include "esp_system.h"

#include "esp_log.h"

#include "esp_task_wdt.h"

#include "driver/uart.h"

#include "hal/uart_types.h" #include "portmacro.h"

#include "string.h"

#include "driver/gpio.h"

#include "pms7003.h"

### 46 File Documentation

#include "bme280.h"

#include "i2c_controller.h" #include "mqtt_client.h"

#include "uart_controller.h" #include "wifi_controller.h" #include "mqtt_controller.h"

Data Structures

- struct ether_measurements_t

Structure to store PMS7003 and BME280 sensors measurements.
- struct ether_descriptor_t

Structure to hold various controller descriptors.
- struct ether_settings_t

Structure for ETHER settings.
- struct ether_state_machine_t

Structure to hold the state machine for PMS7003 and BME280 sensors.
- struct ether_t

Main structure for ETHER containing measurements, descriptors, settings, and state machine.

Enumerations

- enum ether_result_t { ETHER_RESULT_SUCCESS = 0 , ETHER_RESULT_ERROR }

Result codes for ETHER operations.

Functions

- ether_result_t ether_init (ether_t ∗ether)

Initialize the ETHER system.

### 4.3.1 Enumeration Type Documentation

### 4.3.1.1 ether_result_t

enum ether_result_t

Result codes for ETHER operations.

Enumerator

ETHER_RESULT_SUCCESS | Operation was successful.
ETHER_RESULT_ERROR | Operation encountered an error.

### 4.3.2 Function Documentation

### 4.3.2.1 ether_init()

ether_result_t ether_init (

ether_t ∗ ether)

Initialize the ETHER system.

4.4 ether.h | 47

Parameters

out | ether | Pointer to the ETHER structure.

Returns

Result of the initialization.

## 4.4 ether.h

Go to the documentation of this file.

00001 #ifndef INC_ETHER_H
00002 #define INC_ETHER_H
00003
00004 #include "freertos/FreeRTOS.h" 00005 #include "freertos/projdefs.h" 00006 #include "freertos/task.h" 00007 #include "esp_system.h"
00008 #include "esp_log.h"
00009 #include "esp_task_wdt.h" 00010 #include "driver/uart.h" 00011 #include "hal/uart_types.h" 00012 #include "portmacro.h" 00013 #include "string.h"
00014 #include "driver/gpio.h" 00015 #include "pms7003.h
"
00016 #include "bme280.h
"
00017 #include "i2c_controller.h "
00018 #include "mqtt_client.h" 00019 #include "uart_controller.h "
00020 #include "wifi_controller.h "
00021 #include "mqtt_controller.h "
00022
00026 typedef enum

{
00027 | ETHER_RESULT_SUCCESS = 0,
00028 | ETHER_RESULT_ERROR ,
00029 } ether_result_t
| ;
00030
00034 typedef struct
| {
00035 | pms7003_measurements_t pms7003 ;
00036 | bme280_measurements_t bme280 ;
00037 } ether_measurements_t
| ;
00038
00042 typedef struct
| {
00043 | i2c_controller_descriptor_t i2c_controller ;
00044 | mqtt_controller_descriptor_t mqtt_controller

;
00045 uart_controller_descriptor_t uart_controller

;
00046 wifi_controller_descriptor_t wifi_controller

;
00047 } ether_descriptor_t
| ;
00048
00052 typedef struct
| {
00053 | bme280_settings_t bme280 ;
00054 } ether_settings_t
| ;
00055
00059 typedef struct
| {
00060 | pms7003_state_t pms7003 ;
00061 | bme280_state_t bme280 ;
00062 } ether_state_machine_t
| ;
00063
00067 typedef struct
| {
00068 | ether_measurements_t measurements ;
00069 | ether_descriptor_t descriptor ;
00070 | ether_settings_t settings ;
00071 | ether_state_machine_t state_machine ;
00072 } ether_t
| ;
00073
00080 ether_result_t ether_init
| (ether_t *ether);
00081
00082 #endif // !INC_ETHER_H

## 4.5 i2c_controller.h File Reference

#include

<stdint.h

>
#include

<stddef.h

>

### 48 File Documentation

#include "driver/i2c.h"

#include "esp_log.h"

#include "hal/gpio_types.h" #include "hal/i2c_types.h" #include "soc/gpio_num.h"

#include "freertos/projdefs.h"

Data Structures

- struct i2c_controller_descriptor_t

Structure for I2C controller descriptor.

Macros

- #define I2C_CONTROLLER_I2C_ACK_ENABLE (0x01)
- #define I2C_CONTROLLER_I2C_ACK_DISABLE (0x00)
- #define I2C_CONTROLLER_I2C_ACK (0x00)
- #define I2C_CONTROLLER_I2C_NACK (0x01)
- #define I2C_CONTROLLER_MASTER_SCL_IO (GPIO_NUM_22)
- #define I2C_CONTROLLER_MASTER_SDA_IO (GPIO_NUM_21)
- #define I2C_CONTROLLER_MASTER_FREQ_HZ (100000)
- #define I2C_CONTROLLER_MASTER_TX_BUF_DISABLE (0)
- #define I2C_CONTROLLER_MASTER_RX_BUF_DISABLE (0)
- #define I2C_CONTROLLER_CONFIG_DEFAULT

Default configuration for the I2C controller.
- #define I2C_CONTROLLER_DESCRIPTOR_DEFAULT

Default descriptor for the I2C controller.

Enumerations

- enum i2c_controller_result_t { I2C_CONTROLLER_RESULT_SUCCESS = 0 , I2C_CONTROLLER_RESULT_ERROR }

Result codes for I2C controller operations.

Functions

- i2c_controller_result_t i2c_controller_init (const i2c_controller_descriptor_t ∗descriptor)

Initialize the I2C controller.
- i2c_controller_result_t i2c_controller_send (i2c_port_t i2c_num, uint8_t address, uint8_t reg, const uint8_t ∗data, size_t data_len)

Send data over I2C.
- i2c_controller_result_t i2c_controller_receive (i2c_port_t i2c_num, uint8_t address, uint8_t reg, uint8_t ∗data, size_t data_len)

Receive data over I2C.

4.5 i2c_controller.h File Reference | 49

### 4.5.1 Macro Definition Documentation

### 4.5.1.1 I2C_CONTROLLER_CONFIG_DEFAULT

#define I2C_CONTROLLER_CONFIG_DEFAULT

Value:
{ | \
.mode = I2C_MODE_MASTER, | \
.sda_io_num = I2C_CONTROLLER_MASTER_SDA_IO, | \
.sda_pullup_en = GPIO_PULLUP_ENABLE, | \
.scl_io_num = I2C_CONTROLLER_MASTER_SCL_IO, | \
.scl_pullup_en = GPIO_PULLUP_ENABLE, | \
.master.clk_speed = I2C_CONTROLLER_MASTER_FREQ_HZ, | \
}

Default configuration for the I2C controller.

### 4.5.1.2 I2C_CONTROLLER_DESCRIPTOR_DEFAULT

#define I2C_CONTROLLER_DESCRIPTOR_DEFAULT

Value:
{ \
.config = I2C_CONTROLLER_CONFIG_DEFAULT, | \
.i2c_num = I2C_NUM_0, | \
}

Default descriptor for the I2C controller.

### 4.5.1.3 I2C_CONTROLLER_I2C_ACK

#define I2C_CONTROLLER_I2C_ACK (0x00)

### 4.5.1.4 I2C_CONTROLLER_I2C_ACK_DISABLE

#define I2C_CONTROLLER_I2C_ACK_DISABLE (0x00)

### 4.5.1.5 I2C_CONTROLLER_I2C_ACK_ENABLE

#define I2C_CONTROLLER_I2C_ACK_ENABLE (0x01)

### 4.5.1.6 I2C_CONTROLLER_I2C_NACK

#define I2C_CONTROLLER_I2C_NACK (0x01)

### 4.5.1.7 I2C_CONTROLLER_MASTER_FREQ_HZ

#define I2C_CONTROLLER_MASTER_FREQ_HZ (100000)

I2C master clock frequency.

### 50 File Documentation

### 4.5.1.8 I2C_CONTROLLER_MASTER_RX_BUF_DISABLE

#define I2C_CONTROLLER_MASTER_RX_BUF_DISABLE (0)

I2C master doesn't need buffer.

### 4.5.1.9 I2C_CONTROLLER_MASTER_SCL_IO

#define I2C_CONTROLLER_MASTER_SCL_IO (GPIO_NUM_22)

GPIO number for I2C master clock.

### 4.5.1.10 I2C_CONTROLLER_MASTER_SDA_IO

#define I2C_CONTROLLER_MASTER_SDA_IO (GPIO_NUM_21)

GPIO number for I2C master data.

### 4.5.1.11 I2C_CONTROLLER_MASTER_TX_BUF_DISABLE

#define I2C_CONTROLLER_MASTER_TX_BUF_DISABLE (0)

I2C master doesn't need buffer.

### 4.5.2 Enumeration Type Documentation

### 4.5.2.1 i2c_controller_result_t

enum i2c_controller_result_t

Result codes for I2C controller operations.

Enumerator

I2C_CONTROLLER_RESULT_SUCCESS | Operation was successful.
I2C_CONTROLLER_RESULT_ERROR | Operation encountered an error.

### 4.5.3 Function Documentation

### 4.5.3.1 i2c_controller_init()

i2c_controller_result_t i2c_controller_init (

const i2c_controller_descriptor_t ∗ descriptor)

Initialize the I2C controller.

4.5 i2c_controller.h File Reference | 51

Parameters

in | descriptor | Pointer to the I2C controller descriptor.

Returns

Result of the initialization.

### 4.5.3.2 i2c_controller_receive()

i2c_controller_result_t i2c_controller_receive (

i2c_port_t i2c_num,

uint8_t address,

uint8_t reg,

uint8_t ∗ data,

size_t data_len)

Receive data over I2C.

Parameters

in | i2c_num | I2C port number.
in | address | I2C address of the device.
in | reg | Register address to receive data from.
out | data | Pointer to the buffer to store received data.
in | data_len | Length of the data to receive.

Returns

Result of the receive operation.

### 4.5.3.3 i2c_controller_send()

i2c_controller_result_t i2c_controller_send (

i2c_port_t i2c_num,

uint8_t address,

uint8_t reg,

const uint8_t ∗ data,

size_t data_len)

Send data over I2C.

Parameters

in | i2c_num | I2C port number.
in | address | I2C address of the device.
in | reg | Register address to send data to.
in | data | Pointer to the data to send.
in | data_len | Length of the data to send.

Returns

Result of the send operation.

### 52 File Documentation

## 4.6 i2c_controller.h

Go to the documentation of this file.

00001 #ifndef INC_I2C_CONTROLLER_H 00002 #define INC_I2C_CONTROLLER_H 00003
00004 #include <stdint.h>
00005 #include <stddef.h>
00006 #include "driver/i2c.h" 00007 #include "esp_log.h"
00008 #include "hal/gpio_types.h" 00009 #include "hal/i2c_types.h" 00010 #include "soc/gpio_num.h"
00011 #include "freertos/projdefs.h"
00012
00013 #define I2C_CONTROLLER_I2C_ACK_ENABLE | (0x01)
00014 #define I2C_CONTROLLER_I2C_ACK_DISABLE | (0x00)
00015
00016 #define I2C_CONTROLLER_I2C_ACK | (0x00)
00017 #define I2C_CONTROLLER_I2C_NACK | (0x01)
00018
00019 #define I2C_CONTROLLER_MASTER_SCL_IO | (GPIO_NUM_22)
00020 #define I2C_CONTROLLER_MASTER_SDA_IO | (GPIO_NUM_21)
00021 #define I2C_CONTROLLER_MASTER_FREQ_HZ | (100000)
00022 #define I2C_CONTROLLER_MASTER_TX_BUF_DISABLE | (0)
00023 #define I2C_CONTROLLER_MASTER_RX_BUF_DISABLE | (0)
00028 typedef enum {
00029 | I2C_CONTROLLER_RESULT_SUCCESS = 0,
00030 | I2C_CONTROLLER_RESULT_ERROR,
00031 } i2c_controller_result_t;
00032
00036 typedef struct {
00037 | i2c_config_t config;
00038 | i2c_port_t i2c_num;
00039 } i2c_controller_descriptor_t;
00040
00044 #define I2C_CONTROLLER_CONFIG_DEFAULT { | \
00045 | .mode = I2C_MODE_MASTER, | \
00046 | .sda_io_num = I2C_CONTROLLER_MASTER_SDA_IO, | \
00047 | .sda_pullup_en = GPIO_PULLUP_ENABLE, | \
00048 | .scl_io_num = I2C_CONTROLLER_MASTER_SCL_IO, | \
00049 | .scl_pullup_en = GPIO_PULLUP_ENABLE, | \
00050 | .master.clk_speed = I2C_CONTROLLER_MASTER_FREQ_HZ, | \
00051 }
00052
00056 #define I2C_CONTROLLER_DESCRIPTOR_DEFAULT { \
00057 | .config = I2C_CONTROLLER_CONFIG_DEFAULT, | \
00058 | .i2c_num = I2C_NUM_0, | \
00059 }
00060
00067 i2c_controller_result_t i2c_controller_init(const i2c_controller_descriptor_t *descriptor); 00068
00079 i2c_controller_result_t i2c_controller_send(i2c_port_t i2c_num, uint8_t address,
00080 | uint8_t reg, const uint8_t *data,
00081 | size_t data_len);
00082
00093 i2c_controller_result_t i2c_controller_receive(i2c_port_t i2c_num, uint8_t address,
00094 | uint8_t reg, uint8_t *data,
00095 | size_t data_len);
00096
00097 #endif // !INC_I2C_CONTROLLER_H

## 4.7 mqtt_controller.h File Reference

#include <stdio.h>

#include <stdint.h>

#include <stddef.h>

#include <string.h>

#include "esp_wifi.h"

#include "esp_system.h"

#include "nvs_flash.h"

#include "esp_event.h"

#include "esp_netif.h"

#include "lwip/sockets.h"

4.7 mqtt_controller.h File Reference | 53

#include "lwip/dns.h"

#include "lwip/netdb.h"

#include "esp_log.h"

#include "mqtt_client.h"

Data Structures

- struct mqtt_controller_descriptor_t

Structure for MQTT controller descriptor.

Macros

- #define MQTT_CONTROLLER_BROKER_ADDRESS_URI ("mqtt://192.168.235.80:1883")
- #define MQTT_CONTROLLER_MESSAGE_MAX_SIZE (256)
- #define MQTT_CONTROLLER_CONFIG_DEFAULT

Default configuration for the MQTT controller.
- #define MQTT_CONTROLLER_DESCRIPTOR_DEFAULT

Default descriptor for the MQTT controller.

Typedefs

- typedef void(∗ mqtt_controller_event_handler_t) (void ∗, esp_event_base_t, int32_t, void ∗)

Function pointer type for MQTT event handler.

Enumerations

- enum mqtt_controller_result_t { MQTT_CONTROLLER_RESULT_SUCCESS = 0 , MQTT_CONTROLLER_RESULT_ERROR }

Result codes for MQTT controller operations.

Functions

- void mqtt_controller_event_handler (void ∗handler_args, esp_event_base_t base, int32_t event_id, void ∗event_data)

Handle MQTT events.
- mqtt_controller_result_t mqtt_controller_init (mqtt_controller_descriptor_t ∗mqtt_controller_descriptor)

Initialize the MQTT controller.

### 4.7.1 Macro Definition Documentation

### 4.7.1.1 MQTT_CONTROLLER_BROKER_ADDRESS_URI

#define MQTT_CONTROLLER_BROKER_ADDRESS_URI ("mqtt://192.168.235.80:1883")

### 54 File Documentation

### 4.7.1.2 MQTT_CONTROLLER_CONFIG_DEFAULT

#define MQTT_CONTROLLER_CONFIG_DEFAULT

Value:
{ | \
.broker.address.uri = MQTT_CONTROLLER_BROKER_ADDRESS_URI, \ }

Default configuration for the MQTT controller.

### 4.7.1.3 MQTT_CONTROLLER_DESCRIPTOR_DEFAULT

#define MQTT_CONTROLLER_DESCRIPTOR_DEFAULT

Value:
{ | \
.client_config = MQTT_CONTROLLER_CONFIG_DEFAULT, | \
.event_handler = mqtt_controller_event_handler, \ }

Default descriptor for the MQTT controller.

### 4.7.1.4 MQTT_CONTROLLER_MESSAGE_MAX_SIZE

#define MQTT_CONTROLLER_MESSAGE_MAX_SIZE (256)

### 4.7.2 Typedef Documentation

### 4.7.2.1 mqtt_controller_event_handler_t

typedef void(∗ mqtt_controller_event_handler_t) (void ∗, esp_event_base_t, int32_t, void ∗)

Function pointer type for MQTT event handler.

Parameters

in | handler_args | Arguments passed to the handler.
in | base | Event base.
in | event_id | Event ID.
in | event_data | Event data.

### 4.7.3 Enumeration Type Documentation

### 4.7.3.1 mqtt_controller_result_t

enum mqtt_controller_result_t

Result codes for MQTT controller operations.

4.7 mqtt_controller.h File Reference | 55

Enumerator

MQTT_CONTROLLER_RESULT_SUCCESS | Operation was successful.
MQTT_CONTROLLER_RESULT_ERROR | Operation encountered an error.

### 4.7.4 Function Documentation

### 4.7.4.1 mqtt_controller_event_handler()

void mqtt_controller_event_handler (

void ∗ handler_args,

esp_event_base_t base,

int32_t event_id,

void ∗ event_data)

Handle MQTT events.

Parameters

in | handler_args | Arguments passed to the handler.
in | base | Event base.
in | event_id | Event ID.
in | event_data | Event data.

### 4.7.4.2 mqtt_controller_init()

mqtt_controller_result_t mqtt_controller_init (

mqtt_controller_descriptor_t ∗ mqtt_controller_descriptor)

Initialize the MQTT controller.

Parameters

out | mqtt_controller_descriptor | Pointer to the MQTT controller descriptor.

Returns

Result of the initialization.

### 56 File Documentation

## 4.8 mqtt_controller.h

Go to the documentation of this file.

00001 #ifndef INC_MQTT_CONTROLLER_H 00002 #define INC_MQTT_CONTROLLER_H 00003
00004 #include <stdio.h>
00005 #include <stdint.h>
00006 #include <stddef.h>
00007 #include <string.h>
00008 #include "esp_wifi.h" 00009 #include "esp_system.h" 00010 #include "nvs_flash.h" 00011 #include "esp_event.h" 00012 #include "esp_netif.h" 00013
00014 #include "lwip/sockets.h" 00015 #include "lwip/dns.h" 00016 #include "lwip/netdb.h" 00017
00018 #include "esp_log.h"
00019 #include "mqtt_client.h"
00020
00021 #define MQTT_CONTROLLER_BROKER_ADDRESS_URI | ("mqtt://192.168.235.80:1883")
00022 #define MQTT_CONTROLLER_MESSAGE_MAX_SIZE | (256)
00023
00032 typedef void (*mqtt_controller_event_handler_t)(void *, esp_event_base_t, int32_t, void *); 00033
00037 typedef enum {
00038 | MQTT_CONTROLLER_RESULT_SUCCESS = 0,
00039 | MQTT_CONTROLLER_RESULT_ERROR,
00040 } mqtt_controller_result_t;
00041
00045 typedef struct {
00046 | esp_mqtt_client_config_t client_config;
00047 | esp_mqtt_client_handle_t client_handle;
00048 | mqtt_controller_event_handler_t event_handler;
00049 } mqtt_controller_descriptor_t;
00050
00054 #define MQTT_CONTROLLER_CONFIG_DEFAULT | { | \
00055 | .broker.address.uri = MQTT_CONTROLLER_BROKER_ADDRESS_URI, \
00056 }
00057
00061 #define MQTT_CONTROLLER_DESCRIPTOR_DEFAULT | { | \
00062 | .client_config = MQTT_CONTROLLER_CONFIG_DEFAULT, | \
00063 | .event_handler = mqtt_controller_event_handler, \
00064 }
00065
00074 void mqtt_controller_event_handler(void *handler_args, esp_event_base_t base,
00075 | int32_t event_id, void *event_data);
00076
00083 mqtt_controller_result_t mqtt_controller_init(mqtt_controller_descriptor_t *mqtt_controller_descriptor);
00084
00085 #endif // !INC_MQTT_CONTROLLER_H

## 4.9 pms7003.h File Reference

#include <stdint.h>

#include "driver/uart.h"

Data Structures

- union pms7003_frame_request_t

Union representing a PMS7003 frame request.
- union pms7003_frame_answer_t

Union representing a PMS7003 frame answer.
- struct pms7003_measurements_t

Structure representing PMS7003 measurements.

4.9 pms7003.h File Reference | 57

Macros

- #define PMS7003_START_CHARACTER_1 (0x42)
- #define PMS7003_START_CHARACTER_2 (0x4d)
- #define PMS7003_CMD_READ (0xe2)
- #define PMS7003_CMD_CHANGE_MODE (0xe1)
- #define PMS7003_CMD_SLEEP_SET (0xe4)
- #define PMS7003_FRAME_REQUEST_SIZE (0x07)
- #define PMS7003_FRAME_ANSWER_SIZE (0x20)
- #define PMS7003_FRAME_CHECK_CODE_SIZE (0x1e)
- #define PMS7003_FRAME_BYTE_SIZE (0x01)
- #define PMS7003_UART_WAIT_TIMEOUT_MS (0x64)
- #define PMS7003_FRAME_READ

Default frame for reading PMS7003 sensor data.
- #define PMS7003_FRAME_CHANGE_MODE_PASSIVE

Default frame for changing PMS7003 sensor mode to passive.
- #define PMS7003_FRAME_CHANGE_MODE_ACTIVE

Default frame for changing PMS7003 sensor mode to active.
- #define PMS7003_FRAME_SLEEP

Default frame for putting PMS7003 sensor to sleep.
- #define PMS7003_FRAME_WAKEUP

Default frame for waking PMS7003 sensor up.

Typedefs

- typedef int32_t(∗ pms7003_callback_sent_t) (uart_port_t)

Callback function type for handling sent frames.
- typedef int32_t(∗ pms7003_callback_received_t) (uart_port_t, pms7003_frame_answer_t ∗)

Callback function type for handling received frames.

Enumerations

- enum pms7003_result_t {
PMS7003_RESULT_SUCCESS = 0 , PMS7003_RESULT_ERROR , PMS7003_RESULT_PARTIAL_SENT , PMS7003_RESULT_PARTIAL_RECEIVED ,
PMS7003_RESULT_WRONG_CHECK_CODE }

Result codes for PMS7003 sensor operations.
- enum pms7003_status_t { PMS7003_STATUS_OK = 0 , PMS7003_STATUS_READY }

Status codes for PMS7003 sensor.
- enum pms7003_state_t {
PMS7003_STATE_READ_REQUEST = 0 , PMS7003_STATE_CHANGE_MODE_PASSIVE , PMS7003_STATE_CHANGE_MODE_ACTIVE , PMS7003_STATE_SLEEP ,
PMS7003_STATE_WAKEUP , PMS7003_STATE_READ , PMS7003_STATE_UNSET = 0xFF }

States of the PMS7003 sensor.

### 58 File Documentation

Functions

- pms7003_result_t pms7003_frame_send (const pms7003_callback_sent_t handler, uart_port_t uart_num)

Send a PMS7003 frame.
- pms7003_result_t pms7003_frame_receive (const pms7003_callback_received_t handler, uart_port_t uart←-_num, pms7003_frame_answer_t ∗frame)

Receive a PMS7003 frame.
- int32_t pms7003_read_request (uart_port_t uart_num)

Send a read request to the PMS7003 sensor.
- int32_t pms7003_change_mode_passive (uart_port_t uart_num)

Change the PMS7003 mode to passive.
- int32_t pms7003_change_mode_active (uart_port_t uart_num)

Change the PMS7003 mode to active.
- int32_t pms7003_sleep (uart_port_t uart_num)

Put the PMS7003 sensor to sleep.
- int32_t pms7003_wakeup (uart_port_t uart_num)

Wake the PMS7003 sensor up.
- int32_t pms7003_read (uart_port_t uart_num, pms7003_frame_answer_t ∗frame)

Read data from the PMS7003 sensor.

Variables

- const uint8_t start_byte_1
- const uint8_t start_byte_2
- uint8_t command
- uint8_t data_h
- uint8_t data_l
- uint8_t lrch
- uint8_t lrcl
- uint16_t length
- uint16_t data_pm1_standard
- uint16_t data_pm25_standard
- uint16_t data_pm10_standard
- uint16_t data_pm1_atmospheric
- uint16_t data_pm25_atmospheric
- uint16_t data_concentration_unit
- uint16_t data_particles_300nm
- uint16_t data_particles_500nm
- uint16_t data_particles_1000nm
- uint16_t data_particles_2500nm
- uint16_t data_particles_5000nm
- uint16_t data_particles_10000nm
- uint16_t reserved
- uint16_t check_code

### 4.9.1 Macro Definition Documentation

### 4.9.1.1 PMS7003_CMD_CHANGE_MODE

#define PMS7003_CMD_CHANGE_MODE (0xe1)

4.9 pms7003.h File Reference | 59

### 4.9.1.2 PMS7003_CMD_READ

#define PMS7003_CMD_READ (0xe2)

### 4.9.1.3 PMS7003_CMD_SLEEP_SET

#define PMS7003_CMD_SLEEP_SET (0xe4)

### 4.9.1.4 PMS7003_FRAME_ANSWER_SIZE

#define PMS7003_FRAME_ANSWER_SIZE (0x20)

### 4.9.1.5 PMS7003_FRAME_BYTE_SIZE

#define PMS7003_FRAME_BYTE_SIZE (0x01)

### 4.9.1.6 PMS7003_FRAME_CHANGE_MODE_ACTIVE

#define PMS7003_FRAME_CHANGE_MODE_ACTIVE

Value:
{ | \
.start_byte_1 = PMS7003_START_CHARACTER_1, | \
.start_byte_2 = PMS7003_START_CHARACTER_2, | \
.command = PMS7003_CMD_CHANGE_MODE, | \
.data_h = 0x00, | \
.data_l = 0x01, | \
.lrch = 0x01, | \
.lrcl = 0x71, | \
}

Default frame for changing PMS7003 sensor mode to active.

### 4.9.1.7 PMS7003_FRAME_CHANGE_MODE_PASSIVE

#define PMS7003_FRAME_CHANGE_MODE_PASSIVE

Value:
{ | \
.start_byte_1 = PMS7003_START_CHARACTER_1, | \
.start_byte_2 = PMS7003_START_CHARACTER_2, | \
.command = PMS7003_CMD_CHANGE_MODE, | \
.data_h = 0x00, | \
.data_l = 0x00, | \
.lrch = 0x01, | \
.lrcl = 0x70, | \
}

Default frame for changing PMS7003 sensor mode to passive.

### 4.9.1.8 PMS7003_FRAME_CHECK_CODE_SIZE

#define PMS7003_FRAME_CHECK_CODE_SIZE (0x1e)

### 60 File Documentation

### 4.9.1.9 PMS7003_FRAME_READ

#define PMS7003_FRAME_READ

Value:
{ | \
.start_byte_1 = PMS7003_START_CHARACTER_1, | \
.start_byte_2 = PMS7003_START_CHARACTER_2, | \
.command = PMS7003_CMD_READ, | \
.data_h = 0x00, | \
.data_l = 0x00, | \
.lrch = 0x01, | \
.lrcl = 0x71, | \
}

Default frame for reading PMS7003 sensor data.

### 4.9.1.10 PMS7003_FRAME_REQUEST_SIZE

#define PMS7003_FRAME_REQUEST_SIZE (0x07)

### 4.9.1.11 PMS7003_FRAME_SLEEP

#define PMS7003_FRAME_SLEEP

Value:
{ | \
.start_byte_1 = PMS7003_START_CHARACTER_1, | \
.start_byte_2 = PMS7003_START_CHARACTER_2, | \
.command = PMS7003_CMD_SLEEP_SET, | \
.data_h = 0x00, | \
.data_l = 0x00, | \
.lrch = 0x01, | \
.lrcl = 0x73, | \
}

Default frame for putting PMS7003 sensor to sleep.

### 4.9.1.12 PMS7003_FRAME_WAKEUP

#define PMS7003_FRAME_WAKEUP

Value:
{ | \
.start_byte_1 = PMS7003_START_CHARACTER_1, | \
.start_byte_2 = PMS7003_START_CHARACTER_2, | \
.command = PMS7003_CMD_SLEEP_SET, | \
.data_h = 0x00, | \
.data_l = 0x01, | \
.lrch = 0x01, | \
.lrcl = 0x74, | \
}

Default frame for waking PMS7003 sensor up.

### 4.9.1.13 PMS7003_START_CHARACTER_1

#define PMS7003_START_CHARACTER_1 (0x42)

4.9 pms7003.h File Reference | 61

### 4.9.1.14 PMS7003_START_CHARACTER_2

#define PMS7003_START_CHARACTER_2 (0x4d)

### 4.9.1.15 PMS7003_UART_WAIT_TIMEOUT_MS

#define PMS7003_UART_WAIT_TIMEOUT_MS (0x64)

### 4.9.2 Typedef Documentation

### 4.9.2.1 pms7003_callback_received_t

typedef int32_t(∗ pms7003_callback_received_t) (uart_port_t, pms7003_frame_answer_t ∗)

Callback function type for handling received frames.

Parameters

in | uart_num | UART port number.
out | frame | Pointer to the frame answer structure.

Returns

Status code of the operation.

### 4.9.2.2 pms7003_callback_sent_t

typedef int32_t(∗ pms7003_callback_sent_t) (uart_port_t)

Callback function type for handling sent frames.

Parameters

in | uart_num | UART port number.

Returns

Status code of the operation.

### 4.9.3 Enumeration Type Documentation

### 4.9.3.1 pms7003_result_t

enum pms7003_result_t

Result codes for PMS7003 sensor operations.

### 62 File Documentation

Enumerator

PMS7003_RESULT_SUCCESS | Operation was successful.
PMS7003_RESULT_ERROR | Operation encountered an error.
PMS7003_RESULT_PARTIAL_SENT | Partial data sent.
PMS7003_RESULT_PARTIAL_RECEIVED | Partial data received.
PMS7003_RESULT_WRONG_CHECK_CODE | Wrong checksum.

### 4.9.3.2 pms7003_state_t

enum pms7003_state_t

States of the PMS7003 sensor.

Enumerator

PMS7003_STATE_READ_REQUEST | Read request state.
PMS7003_STATE_CHANGE_MODE_PASSIVE | Change to passive mode state.
PMS7003_STATE_CHANGE_MODE_ACTIVE | Change to active mode state.
PMS7003_STATE_SLEEP | Sleep state.
PMS7003_STATE_WAKEUP | Wakeup state.
PMS7003_STATE_READ | Read state.
PMS7003_STATE_UNSET | Unset state.

### 4.9.3.3 pms7003_status_t

enum pms7003_status_t

Status codes for PMS7003 sensor.

Enumerator

PMS7003_STATUS_OK | Status OK.
PMS7003_STATUS_READY | Status Ready.

### 4.9.4 Function Documentation

### 4.9.4.1 pms7003_change_mode_active()

int32_t pms7003_change_mode_active (

uart_port_t uart_num)

Change the PMS7003 mode to active.

4.9 pms7003.h File Reference | 63

Parameters

in | uart_num | UART port number.

Returns

Status code of the operation.

### 4.9.4.2 pms7003_change_mode_passive()

int32_t pms7003_change_mode_passive (

uart_port_t uart_num)

Change the PMS7003 mode to passive.

Parameters

in | uart_num | UART port number.

Returns

Status code of the operation.

### 4.9.4.3 pms7003_frame_receive()

pms7003_result_t pms7003_frame_receive (

const pms7003_callback_received_t handler,

uart_port_t uart_num,

pms7003_frame_answer_t ∗ frame)

Receive a PMS7003 frame.

Parameters

in | handler | Callback function to handle the received frame.
in | uart_num | UART port number.
out | frame | Pointer to the frame answer structure.

Returns

Result of the receive operation.

### 4.9.4.4 pms7003_frame_send()

pms7003_result_t pms7003_frame_send (

const pms7003_callback_sent_t handler,

uart_port_t uart_num)

Send a PMS7003 frame.

### 64 File Documentation

Parameters

in | handler | Callback function to handle the sent frame.
in | uart_num | UART port number.

Returns

Result of the send operation.

### 4.9.4.5 pms7003_read()

int32_t pms7003_read (

uart_port_t uart_num,

pms7003_frame_answer_t ∗ frame)

Read data from the PMS7003 sensor.

Parameters

in | uart_num | UART port number.
out | frame | Pointer to the frame answer structure.

Returns

Status code of the operation.

### 4.9.4.6 pms7003_read_request()

int32_t pms7003_read_request (

uart_port_t uart_num)

Send a read request to the PMS7003 sensor.

Parameters

in | uart_num | UART port number.

Returns

Status code of the operation.

### 4.9.4.7 pms7003_sleep()

int32_t pms7003_sleep (

uart_port_t uart_num)

Put the PMS7003 sensor to sleep.

4.9 pms7003.h File Reference | 65

Parameters

in | uart_num | UART port number.

Returns

Status code of the operation.

### 4.9.4.8 pms7003_wakeup()

int32_t pms7003_wakeup (

uart_port_t uart_num)

Wake the PMS7003 sensor up.

Parameters

in | uart_num | UART port number.

Returns

Status code of the operation.

### 4.9.5 Variable Documentation

### 4.9.5.1 check_code

uint16_t check_code

Checksum code.

### 4.9.5.2 command

uint8_t command

Command byte.

### 4.9.5.3 data_concentration_unit

uint16_t data_concentration_unit

Concentration unit.

### 4.9.5.4 data_h

uint8_t data_h

Data high byte.

### 66 File Documentation

### 4.9.5.5 data_l

uint8_t data_l

Data low byte.

### 4.9.5.6 data_particles_10000nm

uint16_t data_particles_10000nm

Particles count for 10µm.

### 4.9.5.7 data_particles_1000nm

uint16_t data_particles_1000nm

Particles count for 1.0µm.

### 4.9.5.8 data_particles_2500nm

uint16_t data_particles_2500nm

Particles count for 2.5µm.

### 4.9.5.9 data_particles_300nm

uint16_t data_particles_300nm

Particles count for 0.3µm.

### 4.9.5.10 data_particles_5000nm

uint16_t data_particles_5000nm

Particles count for 5.0µm.

### 4.9.5.11 data_particles_500nm

uint16_t data_particles_500nm

Particles count for 0.5µm.

### 4.9.5.12 data_pm10_standard

uint16_t data_pm10_standard

PM10 concentration (standard particles).

4.9 pms7003.h File Reference | 67

### 4.9.5.13 data_pm1_atmospheric

uint16_t data_pm1_atmospheric

PM1.0 concentration (atmospheric particles).

### 4.9.5.14 data_pm1_standard

uint16_t data_pm1_standard

PM1.0 concentration (standard particles).

### 4.9.5.15 data_pm25_atmospheric

uint16_t data_pm25_atmospheric

PM2.5 concentration (atmospheric particles).

### 4.9.5.16 data_pm25_standard

uint16_t data_pm25_standard

PM2.5 concentration (standard particles).

### 4.9.5.17 length

uint16_t length

Length of the frame.

### 4.9.5.18 lrch

uint8_t lrch

High byte of the checksum.

### 4.9.5.19 lrcl

uint8_t lrcl

Low byte of the checksum.

### 4.9.5.20 reserved

uint16_t reserved

Reserved bytes.

### 68 File Documentation

### 4.9.5.21 start_byte_1

uint8_t start_byte_1

Start byte 1.

### 4.9.5.22 start_byte_2

uint8_t start_byte_2

Start byte 2.

## 4.10 pms7003.h

Go to the documentation of this file.

00001 #ifndef INC_PMS7003_H 00002 #define INC_PMS7003_H 00003
00004 #include <stdint.h>
00005 #include "driver/uart.h"
00006
00007 #define PMS7003_START_CHARACTER_1 (0x42) 00008 #define PMS7003_START_CHARACTER_2 (0x4d)
00009 #define PMS7003_CMD_READ | (0xe2)
00010 #define PMS7003_CMD_CHANGE_MODE | (0xe1)
00011 #define PMS7003_CMD_SLEEP_SET | (0xe4)
00012
00013 #define PMS7003_FRAME_REQUEST_SIZE | (0x07)
00014 #define PMS7003_FRAME_ANSWER_SIZE | (0x20)
00015 #define PMS7003_FRAME_CHECK_CODE_SIZE (0x1e)
00016 #define PMS7003_FRAME_BYTE_SIZE | (0x01)
00017
00018 #define PMS7003_UART_WAIT_TIMEOUT_MS (0x64) 00019
00023 typedef union {
00024 | struct {
00025 | const uint8_t start_byte_1;
00026 | const uint8_t start_byte_2;
00027 | uint8_t command;
00028 | uint8_t data_h;
00029 | uint8_t data_l;
00030 | uint8_t lrch;
00031 | uint8_t lrcl;
00032 | /* Verify bytes: add all the bytes except verify bytes. */
00033 | } __attribute__((packed)); | /* Ensure no padding between members. */
00034 | uint8_t buffer_request[PMS7003_FRAME_REQUEST_SIZE];
00035 } pms7003_frame_request_t;
00036
00040 typedef union {
00041 | struct {
00042 | uint8_t start_byte_1;
00043 | uint8_t start_byte_2;
00044 | uint16_t length;
00045 | uint16_t data_pm1_standard;
00046 | uint16_t data_pm25_standard;
00047 | uint16_t data_pm10_standard;
00048 | uint16_t data_pm1_atmospheric;
00049 | uint16_t data_pm25_atmospheric;
00050 | uint16_t data_concentration_unit;
00051 | uint16_t data_particles_300nm;
00052 | uint16_t data_particles_500nm;
00053 | uint16_t data_particles_1000nm;
00054 | uint16_t data_particles_2500nm;
00055 | uint16_t data_particles_5000nm;
00056 | uint16_t data_particles_10000nm;
00057 | uint16_t reserved;
00058 | uint16_t check_code;
00059 | } __attribute__((packed)); | /* Ensure no padding between members. */
00060 | uint8_t buffer_answer[PMS7003_FRAME_ANSWER_SIZE];
00061 } pms7003_frame_answer_t;
00062
00066 typedef struct {
00067 uint16_t pm1;

4.10 pms7003.h | 69
00068 | uint16_t pm25;
00069 | uint16_t pm10;
00070 } pms7003_measurements_t; 00071
00075 typedef enum {
00076 | PMS7003_RESULT_SUCCESS = 0,
00077 | PMS7003_RESULT_ERROR,
00078 | PMS7003_RESULT_PARTIAL_SENT,
00079 | PMS7003_RESULT_PARTIAL_RECEIVED,
00080 | PMS7003_RESULT_WRONG_CHECK_CODE,
00081 } pms7003_result_t;
00082
00086 typedef enum {
00087 | PMS7003_STATUS_OK = 0,
00088 | PMS7003_STATUS_READY,
00089 } pms7003_status_t;
00090
00094 typedef enum {
00095 | PMS7003_STATE_READ_REQUEST = 0,
00096 | PMS7003_STATE_CHANGE_MODE_PASSIVE,
00097 | PMS7003_STATE_CHANGE_MODE_ACTIVE,
00098 | PMS7003_STATE_SLEEP,
00099 | PMS7003_STATE_WAKEUP,
00100 | PMS7003_STATE_READ,
00101 | PMS7003_STATE_UNSET = 0xFF,
00102 } pms7003_state_t;
00103
00107 #define PMS7003_FRAME_READ { | \
00108 | .start_byte_1 = PMS7003_START_CHARACTER_1, | \
00109 | .start_byte_2 = PMS7003_START_CHARACTER_2, | \
00110 | .command = PMS7003_CMD_READ, | \
00111 | .data_h = 0x00, | \
00112 | .data_l = 0x00, | \
00113 | .lrch = 0x01, | \
00114 | .lrcl = 0x71, | \
00115 }
00116
00120 #define PMS7003_FRAME_CHANGE_MODE_PASSIVE { | \
00121 | .start_byte_1 = PMS7003_START_CHARACTER_1, | \
00122 | .start_byte_2 = PMS7003_START_CHARACTER_2, | \
00123 | .command = PMS7003_CMD_CHANGE_MODE, | \
00124 | .data_h = 0x00, | \
00125 | .data_l = 0x00, | \
00126 | .lrch = 0x01, | \
00127 | .lrcl = 0x70, | \
00128 }
00129
00133 #define PMS7003_FRAME_CHANGE_MODE_ACTIVE { | \
00134 | .start_byte_1 = PMS7003_START_CHARACTER_1, | \
00135 | .start_byte_2 = PMS7003_START_CHARACTER_2, | \
00136 | .command = PMS7003_CMD_CHANGE_MODE, | \
00137 | .data_h = 0x00, | \
00138 | .data_l = 0x01, | \
00139 | .lrch = 0x01, | \
00140 | .lrcl = 0x71, | \
00141 }
00142
00146 #define PMS7003_FRAME_SLEEP { | \
00147 | .start_byte_1 = PMS7003_START_CHARACTER_1, | \
00148 | .start_byte_2 = PMS7003_START_CHARACTER_2, | \
00149 | .command = PMS7003_CMD_SLEEP_SET, | \
00150 | .data_h = 0x00, | \
00151 | .data_l = 0x00, | \
00152 | .lrch = 0x01, | \
00153 | .lrcl = 0x73, | \
00154 }
00155
00159 #define PMS7003_FRAME_WAKEUP { | \
00160 | .start_byte_1 = PMS7003_START_CHARACTER_1, | \
00161 | .start_byte_2 = PMS7003_START_CHARACTER_2, | \
00162 | .command = PMS7003_CMD_SLEEP_SET, | \
00163 | .data_h = 0x00, | \
00164 | .data_l = 0x01, | \
00165 | .lrch = 0x01, | \
00166 | .lrcl = 0x74, | \
00167 }
00168
00175 typedef int32_t (*pms7003_callback_sent_t)(uart_port_t);
00176
00184 typedef int32_t (*pms7003_callback_received_t)(uart_port_t, pms7003_frame_answer_t *);
00185
00193 pms7003_result_t pms7003_frame_send(const pms7003_callback_sent_t handler, uart_port_t uart_num); 00194
00203 pms7003_result_t pms7003_frame_receive(const pms7003_callback_received_t handler,
00204 | uart_port_t uart_num, pms7003_frame_answer_t *frame);
00205
00212 int32_t pms7003_read_request(uart_port_t uart_num);

### 70 File Documentation

00213
00220 int32_t pms7003_change_mode_passive(uart_port_t uart_num); 00221
00228 int32_t pms7003_change_mode_active(uart_port_t uart_num); 00229
00236 int32_t pms7003_sleep(uart_port_t uart_num);
00237
00244 int32_t pms7003_wakeup(uart_port_t uart_num);
00245
00253 int32_t pms7003_read(uart_port_t uart_num, pms7003_frame_answer_t *frame); 00254
00255 #endif // !INC_PMS7003_H

## 4.11 state_machine.h File Reference

#include "ether.h"

Functions

- bme280_result_t state_machine_bme280_init (ether_t ∗ether)

Initialize the BME280 sensor within the state machine.
- bme280_result_t state_machine_bme280_reset (ether_t ∗ether)

Reset the BME280 sensor within the state machine.
- bme280_result_t state_machine_bme280_id (ether_t ∗ether)

Read the ID of the BME280 sensor within the state machine.
- bme280_result_t state_machine_bme280_force_mode (ether_t ∗ether)

Set the BME280 sensor to force mode within the state machine.
- bme280_result_t state_machine_bme280_measure_humidity (ether_t ∗ether)

Measure humidity with the BME280 sensor within the state machine.
- bme280_result_t state_machine_bme280_measure_temperature (ether_t ∗ether)

Measure temperature with the BME280 sensor within the state machine.
- bme280_result_t state_machine_bme280_measure_pressure (ether_t ∗ether)

Measure pressure with the BME280 sensor within the state machine.
- bme280_result_t state_machine_bme280_get_compensation_data (ether_t ∗ether)

Get compensation data from the BME280 sensor within the state machine.
- bme280_result_t state_machine_bme280_compensate_humidity (ether_t ∗ether)

Compensate humidity measurement from the BME280 sensor within the state machine.
- bme280_result_t state_machine_bme280_compensate_temperature (ether_t ∗ether)

Compensate temperature measurement from the BME280 sensor within the state machine.
- bme280_result_t state_machine_bme280_compensate_pressure (ether_t ∗ether)

Compensate pressure measurement from the BME280 sensor within the state machine.

### 4.11.1 Function Documentation

### 4.11.1.1 state_machine_bme280_compensate_humidity()

bme280_result_t state_machine_bme280_compensate_humidity (

ether_t ∗ ether)

Compensate humidity measurement from the BME280 sensor within the state machine.

4.11 state_machine.h File Reference | 71

Parameters

out | ether | Pointer to the ether structure.

Returns

Result of the humidity compensation operation.

### 4.11.1.2 state_machine_bme280_compensate_pressure()

bme280_result_t state_machine_bme280_compensate_pressure (

ether_t ∗ ether)

Compensate pressure measurement from the BME280 sensor within the state machine.

Parameters

out | ether | Pointer to the ether structure.

Returns

Result of the pressure compensation operation.

### 4.11.1.3 state_machine_bme280_compensate_temperature()

bme280_result_t state_machine_bme280_compensate_temperature (

ether_t ∗ ether)

Compensate temperature measurement from the BME280 sensor within the state machine.

Parameters

out | ether | Pointer to the ether structure.

Returns

Result of the temperature compensation operation.

### 4.11.1.4 state_machine_bme280_force_mode()

bme280_result_t state_machine_bme280_force_mode (

ether_t ∗ ether)

Set the BME280 sensor to force mode within the state machine.

### 72 File Documentation

Parameters

out | ether | Pointer to the ether structure.

Returns

Result of the force mode operation.

### 4.11.1.5 state_machine_bme280_get_compensation_data()

bme280_result_t state_machine_bme280_get_compensation_data (

ether_t ∗ ether)

Get compensation data from the BME280 sensor within the state machine.

Parameters

out | ether | Pointer to the ether structure.

Returns

Result of the get compensation data operation.

### 4.11.1.6 state_machine_bme280_id()

bme280_result_t state_machine_bme280_id (

ether_t ∗ ether)

Read the ID of the BME280 sensor within the state machine.

Parameters

out | ether | Pointer to the ether structure.

Returns

Result of the ID read operation.

### 4.11.1.7 state_machine_bme280_init()

bme280_result_t state_machine_bme280_init (

ether_t ∗ ether)

Initialize the BME280 sensor within the state machine.

4.11 state_machine.h File Reference | 73

Parameters

out | ether | Pointer to the ether structure.

Returns

Result of the initialization operation.

### 4.11.1.8 state_machine_bme280_measure_humidity()

bme280_result_t state_machine_bme280_measure_humidity (

ether_t ∗ ether)

Measure humidity with the BME280 sensor within the state machine.

Parameters

out | ether | Pointer to the ether structure.

Returns

Result of the humidity measurement operation.

### 4.11.1.9 state_machine_bme280_measure_pressure()

bme280_result_t state_machine_bme280_measure_pressure (

ether_t ∗ ether)

Measure pressure with the BME280 sensor within the state machine.

Parameters

out | ether | Pointer to the ether structure.

Returns

Result of the pressure measurement operation.

### 4.11.1.10 state_machine_bme280_measure_temperature()

bme280_result_t state_machine_bme280_measure_temperature (

ether_t ∗ ether)

Measure temperature with the BME280 sensor within the state machine.

### 74 File Documentation

Parameters

out | ether | Pointer to the ether structure.

Returns

Result of the temperature measurement operation.

### 4.11.1.11 state_machine_bme280_reset()

bme280_result_t state_machine_bme280_reset (

ether_t ∗ ether)

Reset the BME280 sensor within the state machine.

Parameters

out | ether | Pointer to the ether structure.

Returns

Result of the reset operation.

## 4.12 state_machine.h

Go to the documentation of this file.

00001 #ifndef INC_STATE_MACHINE_H 00002 #define INC_STATE_MACHINE_H 00003
00004 #include "ether.h"
00005
00012 bme280_result_t state_machine_bme280_init(ether_t *ether); 00013
00020 bme280_result_t state_machine_bme280_reset(ether_t *ether); 00021
00028 bme280_result_t state_machine_bme280_id(ether_t *ether);
00029
00036 bme280_result_t state_machine_bme280_force_mode(ether_t *ether); 00037
00044 bme280_result_t state_machine_bme280_measure_humidity(ether_t *ether); 00045
00052 bme280_result_t state_machine_bme280_measure_temperature(ether_t *ether); 00053
00060 bme280_result_t state_machine_bme280_measure_pressure(ether_t *ether); 00061
00068 bme280_result_t state_machine_bme280_get_compensation_data(ether_t *ether); 00069
00076 bme280_result_t state_machine_bme280_compensate_humidity(ether_t *ether); 00077
00084 bme280_result_t state_machine_bme280_compensate_temperature(ether_t *ether); 00085
00092 bme280_result_t state_machine_bme280_compensate_pressure(ether_t *ether); 00093
00094 #endif // !INC_STATE_MACHINE_H

## 4.13 uart_controller.h File Reference

#include <stdint.h>

#include <stddef.h>

#include "driver/uart.h"

#include "hal/gpio_types.h" #include "hal/uart_types.h"

4.13 uart_controller.h File Reference | 75

Data Structures

- struct uart_controller_descriptor_t

Structure for UART controller descriptor.

Macros

- #define UART_CONTROLLER_RX_BUF_SIZE (1024)
- #define UART_CONTROLLER_TX_PIN (GPIO_NUM_17)
- #define UART_CONTROLLER_RX_PIN (GPIO_NUM_16)
- #define UART_CONTROLLER_CONFIG_DEFAULT

Default configuration for the UART controller.
- #define UART_CONTROLLER_DESCRIPTOR_DEFAULT

Default descriptor for the UART controller.

Enumerations

- enum uart_controller_result_t { UART_CONTROLLER_RESULT_SUCCESS = 0 , UART_CONTROLLER_RESULT_ERROR }

Result codes for UART controller operations.

Functions

- uart_controller_result_t uart_controller_init (const uart_controller_descriptor_t ∗uart_controller_descriptor)

Initialize the UART controller.

### 4.13.1 Macro Definition Documentation

### 4.13.1.1 UART_CONTROLLER_CONFIG_DEFAULT

#define UART_CONTROLLER_CONFIG_DEFAULT

Value:
{ \
.baud_rate = 9600, | \
.data_bits = UART_DATA_8_BITS, | \
.parity = UART_PARITY_DISABLE, | \
.stop_bits = UART_STOP_BITS_1, | \
.flow_ctrl = UART_HW_FLOWCTRL_DISABLE, | \
.source_clk = UART_SCLK_DEFAULT, | \
}

Default configuration for the UART controller.

### 4.13.1.2 UART_CONTROLLER_DESCRIPTOR_DEFAULT

#define UART_CONTROLLER_DESCRIPTOR_DEFAULT

Value:
{ | \
.uart_config = UART_CONTROLLER_CONFIG_DEFAULT, | \
.uart_port = UART_NUM_2, | \
}

Default descriptor for the UART controller.

### 76 File Documentation

### 4.13.1.3 UART_CONTROLLER_RX_BUF_SIZE

#define UART_CONTROLLER_RX_BUF_SIZE (1024)

### 4.13.1.4 UART_CONTROLLER_RX_PIN

#define UART_CONTROLLER_RX_PIN (GPIO_NUM_16)

### 4.13.1.5 UART_CONTROLLER_TX_PIN

#define UART_CONTROLLER_TX_PIN (GPIO_NUM_17)

### 4.13.2 Enumeration Type Documentation

### 4.13.2.1 uart_controller_result_t

enum uart_controller_result_t

Result codes for UART controller operations.

Enumerator

UART_CONTROLLER_RESULT_SUCCESS | Operation was successful.
UART_CONTROLLER_RESULT_ERROR | Operation encountered an error.

### 4.13.3 Function Documentation

### 4.13.3.1 uart_controller_init()

uart_controller_result_t uart_controller_init (

const uart_controller_descriptor_t ∗ uart_controller_descriptor)

Initialize the UART controller.

Parameters

in | uart_controller_descriptor | Pointer to the UART controller descriptor.

Returns

Result of the initialization operation.

4.14 uart_controller.h | 77

## 4.14 uart_controller.h

Go to the documentation of this file.

00001 #ifndef INC_UART_CONTROLLER_H 00002 #define INC_UART_CONTROLLER_H 00003
00004 #include <stdint.h>
00005 #include <stddef.h>
00006 #include "driver/uart.h" 00007 #include "hal/gpio_types.h"
00008 #include "hal/uart_types.h"
00009
00010 #define UART_CONTROLLER_RX_BUF_SIZE (1024)
00011 #define UART_CONTROLLER_TX_PIN | (GPIO_NUM_17)
00012 #define UART_CONTROLLER_RX_PIN | (GPIO_NUM_16)
00013
00017 typedef enum {
00018 | UART_CONTROLLER_RESULT_SUCCESS = 0,
00019 | UART_CONTROLLER_RESULT_ERROR,
00020 } uart_controller_result_t;
00021
00025 typedef struct {
00026 | uart_config_t uart_config;
00027 | uart_port_t uart_port;
00028 } uart_controller_descriptor_t;
00029
00033 #define UART_CONTROLLER_CONFIG_DEFAULT | { \
00034 | .baud_rate = 9600, | \
00035 | .data_bits = UART_DATA_8_BITS, | \
00036 | .parity = UART_PARITY_DISABLE, | \
00037 | .stop_bits = UART_STOP_BITS_1, | \
00038 | .flow_ctrl = UART_HW_FLOWCTRL_DISABLE, | \
00039 | .source_clk = UART_SCLK_DEFAULT, | \
00040 }
00041
00045 #define UART_CONTROLLER_DESCRIPTOR_DEFAULT | { | \
00046 | .uart_config = UART_CONTROLLER_CONFIG_DEFAULT, | \
00047 | .uart_port = UART_NUM_2, | \
00048 }
00049
00056 uart_controller_result_t uart_controller_init(const uart_controller_descriptor_t *uart_controller_descriptor);
00057
00058 #endif // !INC_UART_CONTROLLER_H

## 4.15 wifi_controller.h File Reference

#include <stdint.h>

#include "esp_system.h"

#include "esp_wifi.h"

#include "esp_event.h"

#include "esp_log.h"

#include "esp_wifi_types.h" #include "nvs_flash.h"

#include "lwip/err.h"

#include "lwip/sys.h"

Data Structures

- struct wifi_controller_descriptor_t

Structure for WIFI controller descriptor.

Macros

- #define WIFI_CONTROLLER_BIT_CONNECTED (BIT0)
- #define WIFI_CONTROLLER_BIT_FAIL (BIT1)
- #define WIFI_CONTROLLER_RETRY_MAX (0x05)
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

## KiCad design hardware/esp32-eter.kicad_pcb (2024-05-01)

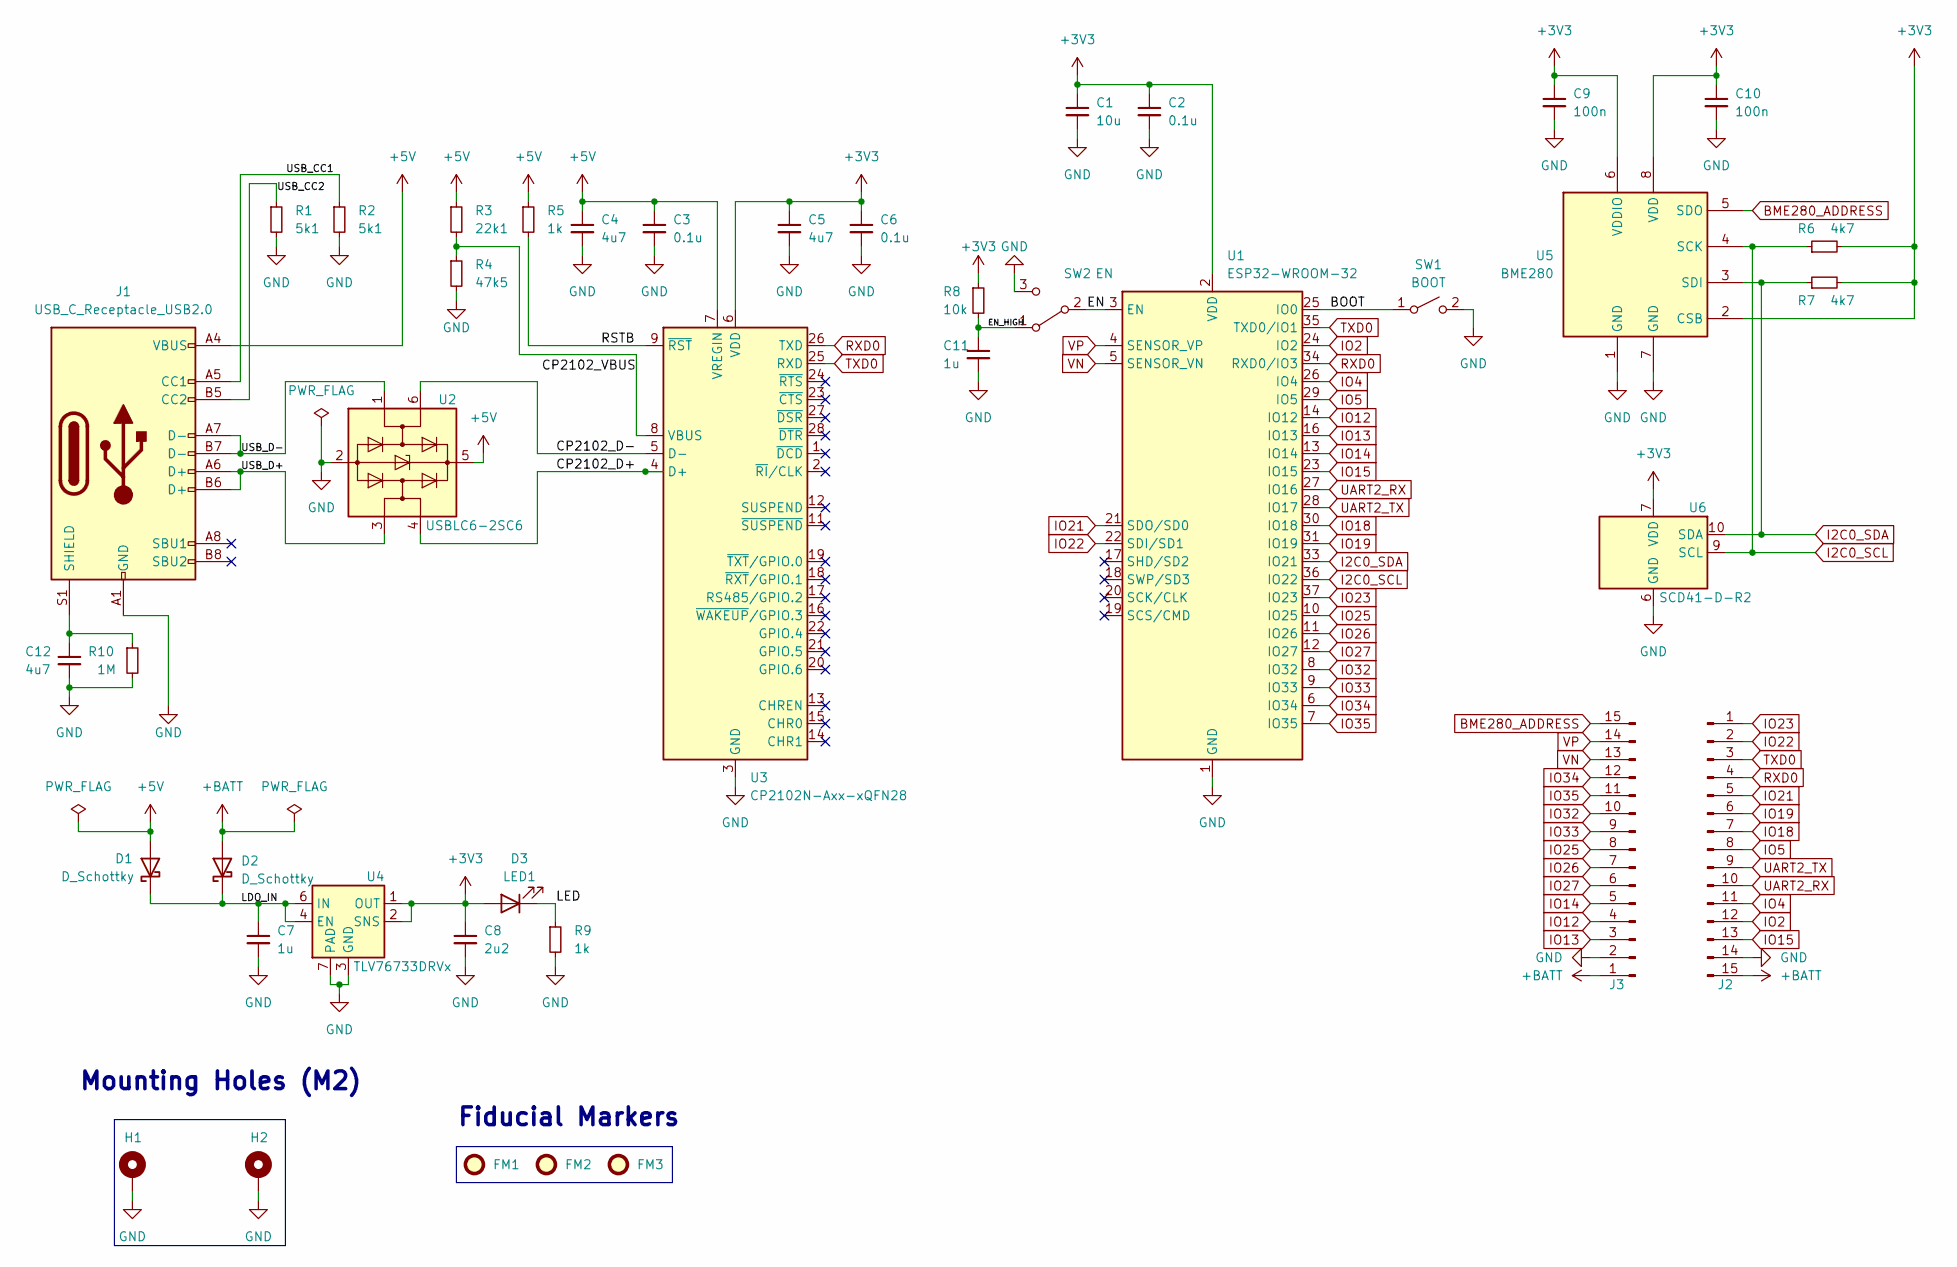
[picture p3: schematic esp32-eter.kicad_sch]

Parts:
C1: 10u; C_0805_2012Metric
C2, C3, C6: 0.1u; C_0402_1005Metric
C4, C5, C12: 4u7; C_0603_1608Metric
C7: 1u; C_0805_2012Metric
C8: 2u2; C_0805_2012Metric
C9, C10: 100n; C_0402_1005Metric
C11: 1u; C_0603_1608Metric
D1, D2: D_Schottky; D_0805_2012Metric
D3: LED1; D_1206_3216Metric
FM1, FM2, FM3: Fiducial; Fiducial_1mm_Mask2mm
H1, H2: MountingHole_Pad; MountingHole_2.2mm_M2
J1: USB_C_Receptacle_USB2.0; USB_C_Receptacle_GCT_USB4105-xx-A_16P_TopMnt_Horizontal
J2, J3: Conn_01x15_Pin; PinSocket_1x15_P2.54mm_Vertical
R1, R2: 5k1; R_0402_1005Metric
R3: 22k1; R_0402_1005Metric
R4: 47k5; R_0402_1005Metric
R5, R9: 1k; R_0402_1005Metric
R6, R7: 4k7; R_0402_1005Metric
R8: 10k; R_0402_1005Metric
R10: 1M; R_0603_1608Metric
SW1: BOOT; SW_Push_SPST_NO_Alps_SKRK
SW2: EN; SW_SPDT_CK-JS102011SAQN
U1: ESP32-WROOM-32
U2: USBLC6-2SC6; SOT-23-6
U3: CP2102N-Axx-xQFN28; QFN-28-1EP_5x5mm_P0.5mm_EP3.35x3.35mm
U4: TLV76733DRVx; WSON-6-1EP_2x2mm_P0.65mm_EP1x1.6mm_ThermalVias
U5: BME280; Bosch_LGA-8_2.5x2.5mm_P0.65mm_ClockwisePinNumbering
U6: SCD41-D-R2; Sensirion_SCD4x-1EP_10.1x10.1mm_P1.25mm_EP4.8x4.8mm

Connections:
+3V3: C1.1, C2.1, C5.1, C6.1, C8.1, C9.1, C10.1, D3.2 (A), R6.2, R7.2, R8.1, U1.2 (VDD), U3.6 (VDD), U4.1 (OUT), U4.2 (SNS), U5.2 (CSB), U5.6 (VDDIO), U5.8 (VDD), U6.7 (VDD), U6.19 (VDD)
+5V: C3.1, C4.1, D1.2 (A), J1.A4 (VBUS), J1.A9 (VBUS), J1.B4 (VBUS), J1.B9 (VBUS), R3.1, R5.1, U2.5 (VBUS), U3.7 (VREGIN)
+BATT: D2.2 (A), J2.15, J3.1
/BOOT: SW1.1 (A), U1.25 (IO0)
/CP2102_D+: U2.4 (I/O2), U3.4 (D+)
/CP2102_D-: U2.6 (I/O1), U3.5 (D-)
/CP2102_VBUS: R3.2, R4.1, U3.8 (VBUS)
/EN: SW2.2 (B), U1.3 (EN)
/EN_HIGH: C11.1, R8.2, SW2.1 (A)
/LDO_IN: C7.1, D1.1 (K), D2.1 (K), U4.4 (EN), U4.6 (IN)
/LED: D3.1 (K), R9.1
/RSTB: R5.2, U3.9 (~RST)
/USB_CC1: J1.A5 (CC1), R2.1
/USB_CC2: J1.B5 (CC2), R1.1
/USB_D+: J1.A6 (D+), J1.B6 (D+), U2.3 (I/O2)
/USB_D-: J1.A7 (D-), J1.B7 (D-), U2.1 (I/O1)
BME280_ADDRESS: J3.15, U5.5 (SDO)
GND: C1.2, C2.2, C3.2, C4.2, C5.2, C6.2, C7.2, C8.2, C9.2, C10.2, C11.2, C12.2, H1.1, H2.1, J1.A1 (GND), J1.A12 (GND), J1.B1 (GND), J1.B12 (GND), J2.14, J3.2, R1.2, R2.2, R4.2, R9.2, R10.2, SW1.2 (B), SW2.3 (C), U1.1 (GND), U1.15 (GND), U1.38 (GND), U1.39 (GND), U2.2 (GND), U3.3 (GND), U3.29 (GND), U4.3 (GND), U4.5 (GND), U4.7 (PAD), U5.1 (GND), U5.7 (GND), U6.6 (GND), U6.20 (GND), U6.21 (GND)
I2C0_SCL: R6.1, U1.36 (IO22), U5.4 (SCK), U6.9 (SCL)
I2C0_SDA: R7.1, U1.33 (IO21), U5.3 (SDI), U6.10 (SDA)
IO2: J2.12, U1.24 (IO2)
IO4: J2.11, U1.26 (IO4)
IO5: J2.8, U1.29 (IO5)
IO12: J3.4, U1.14 (IO12)
IO13: J3.3, U1.16 (IO13)
IO14: J3.5, U1.13 (IO14)
IO15: J2.13, U1.23 (IO15)
IO18: J2.7, U1.30 (IO18)
IO19: J2.6, U1.31 (IO19)
IO21: J2.5, U1.21 (SDO/SD0)
IO22: J2.2, U1.22 (SDI/SD1)
IO23: J2.1, U1.37 (IO23)
IO25: J3.8, U1.10 (IO25)
IO26: J3.7, U1.11 (IO26)
IO27: J3.6, U1.12 (IO27)
IO32: J3.10, U1.8 (IO32)
IO33: J3.9, U1.9 (IO33)
IO34: J3.12, U1.6 (IO34)
IO35: J3.11, U1.7 (IO35)
unnamed: C12.1, J1.S1 (SHIELD), R10.1
RXD0: J2.4, U1.34 (RXD0/IO3), U3.26 (TXD)
TXD0: J2.3, U1.35 (TXD0/IO1), U3.25 (RXD)
UART2_RX: J2.10, U1.27 (IO16)
UART2_TX: J2.9, U1.28 (IO17)
VN: J3.13, U1.5 (SENSOR_VN)
VP: J3.14, U1.4 (SENSOR_VP)

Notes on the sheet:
Mounting Holes (M2)
Fiducial Markers

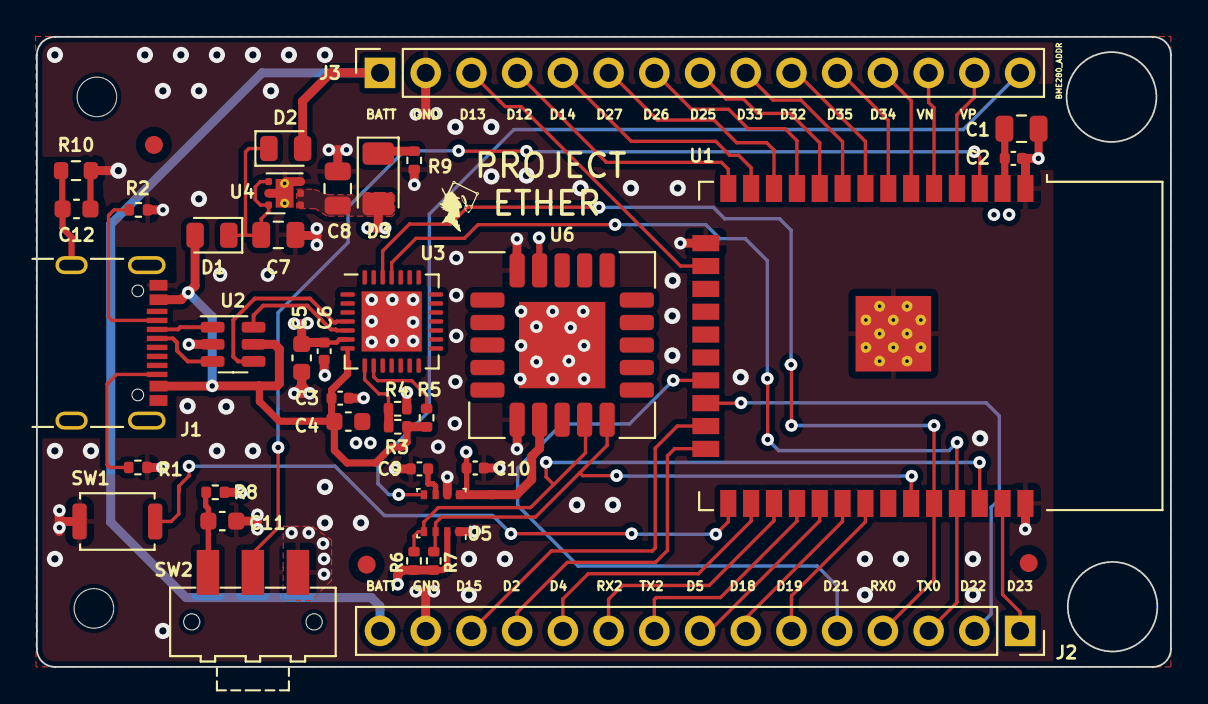
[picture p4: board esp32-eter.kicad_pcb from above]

Board: 4 copper layers, 63.0 x 35.0 mm, 41 parts (0 on the bottom side), 46 nets.

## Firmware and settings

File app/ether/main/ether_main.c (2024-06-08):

#include "ether.h"
#include "state_machine.h"

const TickType_t ether_delay_60s    = pdMS_TO_TICKS(60000);
const TickType_t ether_delay_30s    = pdMS_TO_TICKS(30000);
const TickType_t ether_delay_10s    = pdMS_TO_TICKS(10000);
const TickType_t ether_delay_1s     = pdMS_TO_TICKS(1000);
const TickType_t ether_delay_500ms  = pdMS_TO_TICKS(500);
const TickType_t ether_delay_200ms  = pdMS_TO_TICKS(200);
const TickType_t ether_delay_15ms   = pdMS_TO_TICKS(15);

SemaphoreHandle_t ether_pms7003_semaphore;
SemaphoreHandle_t ether_mqtt_semaphore; 
SemaphoreHandle_t ether_bme280_semaphore;

///////////////////////////////////////////////////////////////////////////////
/* BEGIN OF STATIC FUNCTIONS                                                 */
///////////////////////////////////////////////////////////////////////////////

/* The ether pointer can't be const because of the mqtt_descriptor. */
static void controller_init(ether_t *ether) 
{
  if (!ether) {
    return;
  }

  wifi_controller_init(&ether->descriptor.wifi_controller);
  vTaskDelay(ether_delay_1s);

  uart_controller_init(&ether->descriptor.uart_controller);
  vTaskDelay(ether_delay_1s);

  i2c_controller_init(&ether->descriptor.i2c_controller);
  vTaskDelay(ether_delay_1s);

  mqtt_controller_init(&ether->descriptor.mqtt_controller);
  vTaskDelay(ether_delay_1s);
}

static uint16_t convert_to_little_endian(uint16_t data) 
{
  return ((data & 0x00ff) << 8 | (data & 0xff00) >> 8);
}

static void create_mqtt_message(const ether_t *ether, char *mqtt_message)
{
  if ((!ether) || (!mqtt_message)) {
    return;
  }

  snprintf(mqtt_message, MQTT_CONTROLLER_MESSAGE_MAX_SIZE, 
           "ether measurements:\n\rpm1 = %d\n\rpm2.5 = %d\n\rpm10 = %d\n\rtemp = %f\n\rhum = %f\n\rpress = %f\n\r", 
           ether->measurements.pms7003.pm1, 
           ether->measurements.pms7003.pm25, 
           ether->measurements.pms7003.pm10,
           ether->measurements.bme280.temperature.compensated,
           ether->measurements.bme280.humidity.compensated,
           ether->measurements.bme280.pressure.compensated);
}

///////////////////////////////////////////////////////////////////////////////
/* END OF STATIC FUNCTIONS                                                   */
///////////////////////////////////////////////////////////////////////////////

void ether_mqtt_task(void *arg)
{
  
  static const char *MQTT_TASK_TAG = "MQTT_TASK";
  esp_log_level_set(MQTT_TASK_TAG, ESP_LOG_INFO);

  if (!arg) {
    ESP_LOGE(MQTT_TASK_TAG, "Received null pointer argument");
    vTaskDelete(xTaskGetCurrentTaskHandle());
    return;
  }

  ether_t *ether = arg;
  char mqtt_message[MQTT_CONTROLLER_MESSAGE_MAX_SIZE];
  const char *mqtt_topic = "/topic/ether";
  int result = 0;

  while (1) {
    xSemaphoreTake(ether_mqtt_semaphore, portMAX_DELAY);

#if defined(ETHER_DEBUG)
    ESP_LOGI(MQTT_TASK_TAG, "create data:");
#endif

    create_mqtt_message(ether, mqtt_message);

#if defined(ETHER_DEBUG)
    ESP_LOGI(MQTT_TASK_TAG, "send data:");
#endif

    result = esp_mqtt_client_publish(ether->descriptor.mqtt_controller.client_handle, 
                                     mqtt_topic, mqtt_message, 0, 0, 0);

#if defined(ETHER_DEBUG)
    ESP_LOGI(MQTT_TASK_TAG, "result: %d", result);
#endif

    vTaskDelay(ether_delay_60s);
    xSemaphoreGive(ether_pms7003_semaphore);
  }
}

void ether_bme280_task(void *arg)
{
  static const char *BME280_TASK_TAG = "BME280_TASK";
  esp_log_level_set(BME280_TASK_TAG, ESP_LOG_INFO);

  if (!arg) {
    ESP_LOGE(BME280_TASK_TAG, "Received null pointer argument");
    vTaskDelete(xTaskGetCurrentTaskHandle());
    return;
  }

  ether_t *ether = arg;
  uint8_t retry = 0;
  bme280_result_t result;

  ether->state_machine.bme280 = BME280_STATE_RESET;

  while (1) {
    xSemaphoreTake(ether_bme280_semaphore, portMAX_DELAY);

    while ((ether->state_machine.bme280 != BME280_STATE_UNSET) && (retry < 5)) {
      switch (ether->state_machine.bme280) {
        case BME280_STATE_RESET: {
          result = state_machine_bme280_reset(ether);
          if (result != BME280_RESULT_SUCCESS) {
            ++retry;
          }
          break;
        }
        case BME280_STATE_INIT: {
          result = state_machine_bme280_init(ether);
          if (result != BME280_RESULT_SUCCESS) {
            ++retry;
          }
          break;
        }
        case BME280_STATE_ID: {
          result = state_machine_bme280_id(ether);
          if (result != BME280_RESULT_SUCCESS) {
            ++retry;
          }
          break;
        }
        case BME280_STATE_GET_COMPENSATION_DATA: {
          result = state_machine_bme280_get_compensation_data(ether);
          if (result != BME280_RESULT_SUCCESS) {
            ++retry;
          }
          break;
        }
        case BME280_STATE_FORCE_MODE: {
          result = state_machine_bme280_force_mode(ether);
          if (result != BME280_RESULT_SUCCESS) {
            ++retry;
            break;
          }
          /* 
           * time_measure[max_in_ms] = 1.25 + (2.3 * temp_oversampling) + 
           *                           (2.3 * press_oversampling + 0.575) +
           *                           (2.3 * hum_oversampling + 0.575)
           *
           * time_measure[max_in_ms] = 1.25 + 2.3 + (2.3 + 0.575) + (2.3 + 0.575)
           * time_measure[max_in_ms] = 9.3ms
           */
          vTaskDelay(ether_delay_15ms);
          break;
        }
        case BME280_STATE_MEASURE_HUMIDITY: {
          result = state_machine_bme280_measure_humidity(ether);
          if (result != BME280_RESULT_SUCCESS) {
            ++retry;
          }
          break;
        }
        case BME280_STATE_MEASURE_TEMPERATURE: {
          result = state_machine_bme280_measure_temperature(ether);
          if (result != BME280_RESULT_SUCCESS) {
            ++retry;
          }
          break;
        }
        case BME280_STATE_MEASURE_PRESSURE: {
          result = state_machine_bme280_measure_pressure(ether);
          if (result != BME280_RESULT_SUCCESS) {
            ++retry;
          }
          break;
        }
        case BME280_STATE_COMPENSATE_HUMIDITY: {
          result = state_machine_bme280_compensate_humidity(ether);
          if (result != BME280_RESULT_SUCCESS) {
            ++retry;
          }
          break;
        }
        case BME280_STATE_COMPENSATE_TEMPERATURE: {
          result = state_machine_bme280_compensate_temperature(ether);
          if (result != BME280_RESULT_SUCCESS) {
            ++retry;
          }
          break;
        }
        case BME280_STATE_COMPENSATE_PRESSURE: {
          result = state_machine_bme280_compensate_pressure(ether);
          if (result != BME280_RESULT_SUCCESS) {
            ++retry;
          }
          break;
        }
        default: {
          ether->state_machine.bme280 = BME280_STATE_UNSET;
          break;
        }
      }
    }

    ether->state_machine.bme280 = BME280_STATE_FORCE_MODE;
    retry = 0;

#if defined(ETHER_DEBUG)
    ESP_LOGI(BME280_TASK_TAG, "humidity = %f", ether->measurements.bme280.humidity.compensated);
    ESP_LOGI(BME280_TASK_TAG, "pressure = %f", ether->measurements.bme280.pressure.compensated);
    ESP_LOGI(BME280_TASK_TAG, "temperature = %f\n\r", ether->measurements.bme280.temperature.compensated);
#endif

    vTaskDelay(ether_delay_500ms);

    xSemaphoreGive(ether_mqtt_semaphore);
  }
}

void ether_pms7003_task(void *arg)
{
  static const char *PMS7003_TASK_TAG = "PMS7003_TASK";
  esp_log_level_set(PMS7003_TASK_TAG, ESP_LOG_INFO);

  if (!arg) {
    ESP_LOGE(PMS7003_TASK_TAG, "Received null pointer argument");
    vTaskDelete(xTaskGetCurrentTaskHandle());
    return;
  }

  ether_t *ether = arg;
  pms7003_frame_answer_t frame = { 0 };
  uint8_t retry = 0;
  pms7003_result_t result;

  ether->state_machine.pms7003 = PMS7003_STATE_CHANGE_MODE_PASSIVE;

  while (1) {
    xSemaphoreTake(ether_pms7003_semaphore, portMAX_DELAY);
    
    while ((ether->state_machine.pms7003 != PMS7003_STATE_UNSET) && (retry < 5)) {
      switch (ether->state_machine.pms7003) {
        case PMS7003_STATE_CHANGE_MODE_PASSIVE: {
          result = pms7003_frame_send(&pms7003_change_mode_passive,
                                      ether->descriptor.uart_controller.uart_port);

#if defined(ETHER_DEBUG)
          ESP_LOGI(PMS7003_TASK_TAG, "PMS7003_STATE_CHANGE_MODE_PASSIVE");
          ESP_LOGI(PMS7003_TASK_TAG, "RESULT: %d", result);
#endif

          if (result != PMS7003_RESULT_SUCCESS) {
            ++retry;
            break;
          }

          ether->state_machine.pms7003 = PMS7003_STATE_WAKEUP;
          vTaskDelay(ether_delay_500ms);
          break;
        }
        case PMS7003_STATE_CHANGE_MODE_ACTIVE: {
          result = pms7003_frame_send(&pms7003_change_mode_active,
                                      ether->descriptor.uart_controller.uart_port);

#if defined(ETHER_DEBUG)
          ESP_LOGI(PMS7003_TASK_TAG, "PMS7003_STATE_CHANGE_MODE_ACTIVE");
          ESP_LOGI(PMS7003_TASK_TAG, "RESULT: %d", result);
#endif
          if (result != PMS7003_RESULT_SUCCESS) {
            ++retry;
            break;
          }

          ether->state_machine.pms7003 = PMS7003_STATE_WAKEUP;
          vTaskDelay(ether_delay_500ms);
          break;
        }
        case PMS7003_STATE_WAKEUP: {
          result = pms7003_frame_send(&pms7003_wakeup, ether->descriptor.uart_controller.uart_port);

#if defined(ETHER_DEBUG)
          ESP_LOGI(PMS7003_TASK_TAG, "PMS7003_STATE_WAKEUP");
          ESP_LOGI(PMS7003_TASK_TAG, "RESULT: %d", result);
#endif
          if (result != PMS7003_RESULT_SUCCESS) {
            ++retry;
            break;
          }

          ether->state_machine.pms7003 = PMS7003_STATE_READ_REQUEST;
          /* Wait at least 30s to get stable data. */
          vTaskDelay(ether_delay_30s);
          break;
        }
        case PMS7003_STATE_READ_REQUEST: {
          for (uint8_t i = 0; i < 5; i++) {
            /* Avoid getting unstable data. */
            uart_flush(ether->descriptor.uart_controller.uart_port);
            result = pms7003_frame_send(&pms7003_read_request, ether->descriptor.uart_controller.uart_port);
            vTaskDelay(ether_delay_500ms);
          }

#if defined(ETHER_DEBUG)
          ESP_LOGI(PMS7003_TASK_TAG, "PMS7003_STATE_READ_REQUEST");
          ESP_LOGI(PMS7003_TASK_TAG, "RESULT: %d", result);
#endif

          if (result != PMS7003_RESULT_SUCCESS) {
            ++retry;
            break;
          }

          ether->state_machine.pms7003 = PMS7003_STATE_READ;
          break;
        }
        case PMS7003_STATE_READ: {
          result = pms7003_frame_receive(&pms7003_read, ether->descriptor.uart_controller.uart_port, &frame);

#if defined(ETHER_DEBUG)
          ESP_LOGI(PMS7003_TASK_TAG, "PMS7003_STATE_READ");
          ESP_LOGI(PMS7003_TASK_TAG, "RESULT: %d", result);
#endif

          if (result != PMS7003_RESULT_SUCCESS) {
            ++retry;
            break;
          }

          ether->state_machine.pms7003 = PMS7003_STATE_SLEEP;
          vTaskDelay(ether_delay_500ms);
          break;
        }
        case PMS7003_STATE_SLEEP: {
          result = pms7003_frame_send(&pms7003_sleep, ether->descriptor.uart_controller.uart_port);

#if defined(ETHER_DEBUG)
          ESP_LOGI(PMS7003_TASK_TAG, "PMS7003_STATE_SLEEP");
          ESP_LOGI(PMS7003_TASK_TAG, "RESULT: %d", result);
#endif

          if (result != PMS7003_RESULT_SUCCESS) {
            ++retry;
            break;
          }

          ether->state_machine.pms7003 = PMS7003_STATE_UNSET;
          vTaskDelay(ether_delay_500ms);
          break;
        }
        default: {
#if defined(ETHER_DEBUG)
          ESP_LOGI(PMS7003_TASK_TAG, "default");
#endif
          ether->state_machine.pms7003 = PMS7003_STATE_UNSET;
          vTaskDelay(ether_delay_500ms);
          break;
        }
      }
    }
    
    ether->measurements.pms7003.pm1   = convert_to_little_endian(frame.data_pm1_standard);
    ether->measurements.pms7003.pm25  = convert_to_little_endian(frame.data_pm25_standard);
    ether->measurements.pms7003.pm10  = convert_to_little_endian(frame.data_pm10_standard);

    ether->state_machine.pms7003 = PMS7003_STATE_WAKEUP;

    retry = 0;

    xSemaphoreGive(ether_bme280_semaphore);
  }
}

void app_main(void) 
{
  ether_t ether;

  esp_task_wdt_deinit();

  esp_err_t ret = nvs_flash_init();
  if (ret == ESP_ERR_NVS_NO_FREE_PAGES || ret == ESP_ERR_NVS_NEW_VERSION_FOUND) {
    ESP_ERROR_CHECK(nvs_flash_erase());
    ret = nvs_flash_init();
  }
  ESP_ERROR_CHECK(ret);

  ether_init(&ether);
  controller_init(&ether);

  ether_pms7003_semaphore = xSemaphoreCreateBinary();
  ether_mqtt_semaphore    = xSemaphoreCreateBinary();
  ether_bme280_semaphore  = xSemaphoreCreateBinary();

  xSemaphoreGive(ether_pms7003_semaphore);

  xTaskCreate(ether_pms7003_task, "pms7003_task", 4096 * 2, &ether, configMAX_PRIORITIES - 1, NULL);
  xTaskCreate(ether_mqtt_task, "mqtt_task", 4096 * 2, &ether, configMAX_PRIORITIES - 1, NULL);
  xTaskCreate(ether_bme280_task, "bme280_task", 4096 * 2, &ether, configMAX_PRIORITIES - 1, NULL);

  while(1);
}

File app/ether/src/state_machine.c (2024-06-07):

#include "state_machine.h"

static const char *STATE_MACHINE_TAG = "STATE_MACHINE";

bme280_result_t state_machine_bme280_init(ether_t *ether)
{
  if (!ether) {
    return BME280_RESULT_ERROR;
  }

  bme280_result_t result = bme280_init(ether->descriptor.i2c_controller.i2c_num, &ether->settings.bme280);

#if defined(ETHER_DEBUG)
  ESP_LOGI(STATE_MACHINE_TAG, "BME280_STATE_INIT");
  ESP_LOGI(STATE_MACHINE_TAG, "RESULT: %d", result);
#endif

  if (result != BME280_RESULT_SUCCESS) {
    return BME280_RESULT_ERROR;
  }

  ether->state_machine.bme280 = BME280_STATE_ID;

  return BME280_RESULT_SUCCESS;
}


bme280_result_t state_machine_bme280_reset(ether_t *ether)
{
  if (!ether) {
    return BME280_RESULT_ERROR;
  }

  bme280_result_t result = bme280_reset(ether->descriptor.i2c_controller.i2c_num);

#if defined(ETHER_DEBUG)
  ESP_LOGI(STATE_MACHINE_TAG, "BME280_STATE_RESET");
  ESP_LOGI(STATE_MACHINE_TAG, "RESULT: %d", result);
#endif

  if (result != BME280_RESULT_SUCCESS) {
    return BME280_RESULT_ERROR;
  }

  ether->state_machine.bme280 = BME280_STATE_INIT;

  return BME280_RESULT_SUCCESS;
}


bme280_result_t state_machine_bme280_id(ether_t *ether)
{
  if (!ether) {
    return BME280_RESULT_ERROR;
  }

  uint8_t data = 0;
  bme280_result_t result = bme280_id(ether->descriptor.i2c_controller.i2c_num, &data, sizeof(data));

#if defined(ETHER_DEBUG)
  ESP_LOGI(STATE_MACHINE_TAG, "BME280_STATE_ID");
  ESP_LOGI(STATE_MACHINE_TAG, "RESULT: %d", result);
#endif

  if ((result != BME280_RESULT_SUCCESS) || (data != BME280_DATA_ID)) {
    return BME280_RESULT_ERROR;
  }

  ether->state_machine.bme280 = BME280_STATE_GET_COMPENSATION_DATA;

  return BME280_RESULT_SUCCESS;
}


bme280_result_t state_machine_bme280_force_mode(ether_t *ether)
{
  if (!ether) {
    return BME280_RESULT_ERROR;
  }

  bme280_result_t result = bme280_force_mode(ether->descriptor.i2c_controller.i2c_num, &ether->settings.bme280);

#if defined(ETHER_DEBUG)
  ESP_LOGI(STATE_MACHINE_TAG, "BME280_STATE_FORCE_MODE");
  ESP_LOGI(STATE_MACHINE_TAG, "RESULT: %d", result);
#endif

  if (result != BME280_RESULT_SUCCESS) {
    return BME280_RESULT_ERROR;
  }

  ether->state_machine.bme280 = BME280_STATE_MEASURE_HUMIDITY;

  return BME280_RESULT_SUCCESS;
}


bme280_result_t state_machine_bme280_measure_humidity(ether_t *ether)
{
  if (!ether) {
    return BME280_RESULT_ERROR;
  }

  bme280_result_t result = bme280_measure_humidity(ether->descriptor.i2c_controller.i2c_num, 
                                                   &ether->measurements.bme280.humidity);

#if defined(ETHER_DEBUG)
  ESP_LOGI(STATE_MACHINE_TAG, "BME280_STATE_MEASURE_HUMIDITY");
  ESP_LOGI(STATE_MACHINE_TAG, "RESULT: %d", result);
#endif

  if (result != BME280_RESULT_SUCCESS) {
    return BME280_RESULT_ERROR;
  }

  ether->state_machine.bme280 = BME280_STATE_MEASURE_TEMPERATURE;

  return BME280_RESULT_SUCCESS;
}


bme280_result_t state_machine_bme280_measure_temperature(ether_t *ether)
{
  if (!ether) {
    return BME280_RESULT_ERROR;
  }

  bme280_result_t result = bme280_measure_temperature(ether->descriptor.i2c_controller.i2c_num, 
                                                      &ether->measurements.bme280.temperature);

#if defined(ETHER_DEBUG)
  ESP_LOGI(STATE_MACHINE_TAG, "BME280_STATE_MEASURE_TEMPERATURE");
  ESP_LOGI(STATE_MACHINE_TAG, "RESULT: %d", result);
#endif

  if (result != BME280_RESULT_SUCCESS) {
    return BME280_RESULT_ERROR;
  }

  ether->state_machine.bme280 = BME280_STATE_MEASURE_PRESSURE;

  return BME280_RESULT_SUCCESS;
}


bme280_result_t state_machine_bme280_measure_pressure(ether_t *ether)
{
  if (!ether) {
    return BME280_RESULT_ERROR;
  }

  bme280_result_t result = bme280_measure_pressure(ether->descriptor.i2c_controller.i2c_num, 
                                                   &ether->measurements.bme280.pressure);

#if defined(ETHER_DEBUG)
  ESP_LOGI(STATE_MACHINE_TAG, "BME280_STATE_MEASURE_PRESSURE");
  ESP_LOGI(STATE_MACHINE_TAG, "RESULT: %d", result);
#endif

  if (result != BME280_RESULT_SUCCESS) {
    return BME280_RESULT_ERROR;
  }

  ether->state_machine.bme280 = BME280_STATE_COMPENSATE_HUMIDITY;

  return BME280_RESULT_SUCCESS;
}


bme280_result_t state_machine_bme280_get_compensation_data(ether_t *ether)
{
  if (!ether) {
    return BME280_RESULT_ERROR;
  }

  bme280_result_t result = bme280_get_compensation_data(ether->descriptor.i2c_controller.i2c_num, 
                                                        &ether->measurements.bme280.compensator);

#if defined(ETHER_DEBUG)
  ESP_LOGI(STATE_MACHINE_TAG, "BME280_STATE_GET_COMPENSATION_DATA");
  ESP_LOGI(STATE_MACHINE_TAG, "RESULT: %d", result);
#endif

  if (result != BME280_RESULT_SUCCESS) {
    return BME280_RESULT_ERROR;
  }

  ether->state_machine.bme280 = BME280_STATE_FORCE_MODE;

  return BME280_RESULT_SUCCESS;
}


bme280_result_t state_machine_bme280_compensate_humidity(ether_t *ether)
{
  if (!ether) {
    return BME280_RESULT_ERROR;
  }

  bme280_result_t result = bme280_compensate_humidity(&ether->measurements.bme280.compensator, 
                                                      &ether->measurements.bme280.humidity);

#if defined(ETHER_DEBUG)
  ESP_LOGI(STATE_MACHINE_TAG, "BME280_STATE_COMPENSATE_HUMIDITY");
  ESP_LOGI(STATE_MACHINE_TAG, "RESULT: %d", result);
#endif

  if (result != BME280_RESULT_SUCCESS) {
    return BME280_RESULT_ERROR;
  }

  ether->state_machine.bme280 = BME280_STATE_COMPENSATE_TEMPERATURE;

  return BME280_RESULT_SUCCESS;
}


bme280_result_t state_machine_bme280_compensate_temperature(ether_t *ether)
{
  if (!ether) {
    return BME280_RESULT_ERROR;
  }

  bme280_result_t result = bme280_compensate_temperature(&ether->measurements.bme280.compensator, 
                                                         &ether->measurements.bme280.temperature);

#if defined(ETHER_DEBUG)
  ESP_LOGI(STATE_MACHINE_TAG, "BME280_STATE_COMPENSATE_TEMPERATURE");
  ESP_LOGI(STATE_MACHINE_TAG, "RESULT: %d", result);
#endif

  if (result != BME280_RESULT_SUCCESS) {
    return BME280_RESULT_ERROR;
  }

  ether->state_machine.bme280 = BME280_STATE_COMPENSATE_PRESSURE;

  return BME280_RESULT_SUCCESS;
}


bme280_result_t state_machine_bme280_compensate_pressure(ether_t *ether)
{
  if (!ether) {
    return BME280_RESULT_ERROR;
  }

  bme280_result_t result = bme280_compensate_pressure(&ether->measurements.bme280.compensator, 
                                                      &ether->measurements.bme280.pressure);

#if defined(ETHER_DEBUG)
  ESP_LOGI(STATE_MACHINE_TAG, "BME280_STATE_COMPENSATE_PRESSURE");
  ESP_LOGI(STATE_MACHINE_TAG, "RESULT: %d", result);
#endif

  if (result != BME280_RESULT_SUCCESS) {
    return BME280_RESULT_ERROR;
  }

  ether->state_machine.bme280 = BME280_STATE_UNSET;

  return BME280_RESULT_SUCCESS;
}

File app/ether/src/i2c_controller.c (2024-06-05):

#include "i2c_controller.h"

static const TickType_t ticks = pdMS_TO_TICKS(10000);

i2c_controller_result_t i2c_controller_init(const i2c_controller_descriptor_t *descriptor) 
{
  if (!descriptor) {
    return I2C_CONTROLLER_RESULT_ERROR;
  }

  esp_err_t result;
  static const char *I2C_CONTROLLER_CONFIG_TAG = "I2C_CONTROLLER_CONFIG";

  result = i2c_param_config(descriptor->i2c_num, &descriptor->config);
  if (result != ESP_OK) {
    ESP_LOGI(I2C_CONTROLLER_CONFIG_TAG, "i2c_param_config result = 0x%x", result); 
    return I2C_CONTROLLER_RESULT_ERROR;
  }

  result = i2c_driver_install(descriptor->i2c_num, descriptor->config.mode, 
                              I2C_CONTROLLER_MASTER_RX_BUF_DISABLE, 
                              I2C_CONTROLLER_MASTER_TX_BUF_DISABLE, 0);
  if (result != ESP_OK) {
    ESP_LOGI(I2C_CONTROLLER_CONFIG_TAG, "i2c_driver_install result = 0x%x", result); 
    return I2C_CONTROLLER_RESULT_ERROR;
  }

  ESP_LOGI(I2C_CONTROLLER_CONFIG_TAG, "i2c_controller_init: OK"); 
  return I2C_CONTROLLER_RESULT_SUCCESS;
}

i2c_controller_result_t i2c_controller_send(i2c_port_t i2c_num, uint8_t address, 
                                            uint8_t reg, const uint8_t *data, 
                                            size_t data_len) 
{
  esp_err_t result;
  static const char *I2C_CONTROLLER_SEND_TAG = "I2C_CONTROLLER_SEND";

  i2c_cmd_handle_t cmd = i2c_cmd_link_create();

  result = i2c_master_start(cmd);
  if (result != ESP_OK) {
    ESP_LOGI(I2C_CONTROLLER_SEND_TAG, "i2c_master_start result = 0x%x", result); 
    return I2C_CONTROLLER_RESULT_ERROR;
  }

  /* Send device address. */
  result = i2c_master_write_byte(cmd, ((address << 1) | I2C_MASTER_WRITE), I2C_CONTROLLER_I2C_ACK_ENABLE);
  if (result != ESP_OK) {
    ESP_LOGI(I2C_CONTROLLER_SEND_TAG, "i2c_master_write_byte result = 0x%x", result); 
    return I2C_CONTROLLER_RESULT_ERROR;
  }

  /* Send register address. */
  result = i2c_master_write_byte(cmd, reg, I2C_CONTROLLER_I2C_ACK_ENABLE);
  if (result != ESP_OK) {
    ESP_LOGI(I2C_CONTROLLER_SEND_TAG, "i2c_master_write_byte result = 0x%x", result); 
    return I2C_CONTROLLER_RESULT_ERROR;
  }

  result = i2c_master_write(cmd, data, data_len, I2C_CONTROLLER_I2C_ACK_ENABLE);
  if (result != ESP_OK) {
    ESP_LOGI(I2C_CONTROLLER_SEND_TAG, "i2c_master_write_byte result = 0x%x", result); 
    return I2C_CONTROLLER_RESULT_ERROR;
  }

  result = i2c_master_stop(cmd);
  if (result != ESP_OK) {
    ESP_LOGI(I2C_CONTROLLER_SEND_TAG, "i2c_master_stop result = 0x%x", result); 
    return I2C_CONTROLLER_RESULT_ERROR;
  }

  result = i2c_master_cmd_begin(i2c_num, cmd, ticks);
  if (result != ESP_OK) {
    ESP_LOGI(I2C_CONTROLLER_SEND_TAG, "i2c_master_cmd_begin result = 0x%x", result); 
    return I2C_CONTROLLER_RESULT_ERROR;
  }

  i2c_cmd_link_delete(cmd);

  ESP_LOGI(I2C_CONTROLLER_SEND_TAG, "i2c_controller_send: OK"); 

  return I2C_CONTROLLER_RESULT_SUCCESS;
}

i2c_controller_result_t i2c_controller_receive(i2c_port_t i2c_num, uint8_t address, 
                                               uint8_t reg, uint8_t *data, 
                                               size_t data_len) 
{
  esp_err_t result;
  static const char *I2C_CONTROLLER_RECEIVE_TAG = "I2C_CONTROLLER_RECEIVE";

  i2c_cmd_handle_t cmd = i2c_cmd_link_create();

  result = i2c_master_start(cmd);
  if (result != ESP_OK) {
    ESP_LOGI(I2C_CONTROLLER_RECEIVE_TAG, "i2c_master_start result = 0x%x", result); 
    return I2C_CONTROLLER_RESULT_ERROR;
  }

  /* Send device address. */
  result = i2c_master_write_byte(cmd, ((address << 1) | I2C_MASTER_WRITE), I2C_CONTROLLER_I2C_ACK_ENABLE);
  if (result != ESP_OK) {
    ESP_LOGI(I2C_CONTROLLER_RECEIVE_TAG, "i2c_master_write_byte result = 0x%x", result); 
    return I2C_CONTROLLER_RESULT_ERROR;
  }

  /* Send register address. */
  result = i2c_master_write(cmd, &reg, 1, I2C_CONTROLLER_I2C_ACK_ENABLE);
  if (result != ESP_OK) {
    ESP_LOGI(I2C_CONTROLLER_RECEIVE_TAG, "i2c_master_write_byte result = 0x%x", result); 
    return I2C_CONTROLLER_RESULT_ERROR;
  }

  result = i2c_master_stop(cmd);
  if (result != ESP_OK) {
    ESP_LOGI(I2C_CONTROLLER_RECEIVE_TAG, "i2c_master_stop result = 0x%x", result); 
    return I2C_CONTROLLER_RESULT_ERROR;
  }

  result = i2c_master_cmd_begin(i2c_num, cmd, ticks);
  if (result != ESP_OK) {
    ESP_LOGI(I2C_CONTROLLER_RECEIVE_TAG, "i2c_master_cmd_begin result = 0x%x", result); 
    return I2C_CONTROLLER_RESULT_ERROR;
  }

  i2c_cmd_link_delete(cmd);
  cmd = i2c_cmd_link_create();

  result = i2c_master_start(cmd);
  if (result != ESP_OK) {
    ESP_LOGI(I2C_CONTROLLER_RECEIVE_TAG, "i2c_master_start result = 0x%x", result); 
    return I2C_CONTROLLER_RESULT_ERROR;
  }

  /* Send device address. */
  result = i2c_master_write_byte(cmd, ((address << 1) | I2C_MASTER_READ), I2C_CONTROLLER_I2C_ACK_ENABLE);
  if (result != ESP_OK) {
    ESP_LOGI(I2C_CONTROLLER_RECEIVE_TAG, "i2c_master_write_byte result = 0x%x", result); 
    return I2C_CONTROLLER_RESULT_ERROR;
  }

  if (data_len > 1) {
    result = i2c_master_read(cmd, data, data_len - 1, I2C_CONTROLLER_I2C_ACK);
    if (result != ESP_OK) {
      ESP_LOGI(I2C_CONTROLLER_RECEIVE_TAG, "i2c_master_read result = 0x%x", result); 
      return I2C_CONTROLLER_RESULT_ERROR;
    }
  }

  result = i2c_master_read_byte(cmd, data + (data_len - 1), I2C_CONTROLLER_I2C_NACK);
  if (result != ESP_OK) {
    ESP_LOGI(I2C_CONTROLLER_RECEIVE_TAG, "i2c_master_read_byte result = 0x%x", result); 
    return I2C_CONTROLLER_RESULT_ERROR;
  }

  result = i2c_master_stop(cmd);
  if (result != ESP_OK) {
    ESP_LOGI(I2C_CONTROLLER_RECEIVE_TAG, "i2c_master_stop result = 0x%x", result); 
    return I2C_CONTROLLER_RESULT_ERROR;
  }

  result = i2c_master_cmd_begin(i2c_num, cmd, ticks);
  if (result != ESP_OK) {
    ESP_LOGI(I2C_CONTROLLER_RECEIVE_TAG, "i2c_master_cmd_begin result = 0x%x", result); 
    return I2C_CONTROLLER_RESULT_ERROR;
  }

  i2c_cmd_link_delete(cmd);

  ESP_LOGI(I2C_CONTROLLER_RECEIVE_TAG, "i2c_controller_receive: OK"); 

  return I2C_CONTROLLER_RESULT_SUCCESS;
}

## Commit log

2024-05-01 PROJECT-ETHER-001: Add current work.
    [esp32-eter-B_Cu.gbr, esp32-eter-B_Mask.gbr, esp32-eter-B_Paste.gbr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]
2024-05-01 PROJECT-ETHER-002: Clean manufacturing directory.
    [esp32-eter-B_Cu.gbr, esp32-eter-B_Mask.gbr, esp32-eter-B_Paste.gbr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]
2024-05-03 PROJECT-ETHER-UART-001: Add uart_controller files, combine two sensors in demo.
2024-05-12 PROJECT-ETHER-MAIN: Correct the doxygen comments.
    [i2c_controller.h, uart_controller.h]
2024-05-26 PROJECT-ETHER-MAIN: Create mqtt task for sending data to mqtt broker.
    [ether_main.c]
2024-05-26 PROJECT-ETHER-MAIN: Change the resistor value for the led diode.
    [esp32-eter.kicad_sch]
2024-06-05 PROJECT-ETHER-REFACTOR: Add the state machines for sensors.
2024-06-07 PROJECT-ETHER-REFACTOR: Fix bme280 state machine transition from reset to init.
    [ether_main.c, state_machine.c]
2024-06-08 PROJECT-ETHER-REFACTOR: Add doxygen documentation for BME280 sensor.
2024-06-08 PROJECT-ETHER-REFACTOR: Add doxygen documentation for i2c_controller.
2024-06-08 PROJECT-ETHER-REFACTOR: Add doxygen documentation for pms7003 sensor.
2024-06-08 PROJECT-ETHER-REFACTOR: Add doxygen documentation for uart and wifi controllers.
2026-04-12 doc: Add idea schematic
